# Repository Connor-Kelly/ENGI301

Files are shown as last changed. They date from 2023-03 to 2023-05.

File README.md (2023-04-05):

# Music Box
## Repo: 
This reposistory is fairly simple, docs are in /docs and source code in /src. There is also some royalty free music contained within the /sample_music directory, being used solely for testing purposes. There is also a /ipynb_testing_files directory which contains a variety of jupyter notebook files which can be used for easily testing and iterating through code.

## Story:
For my ENGI 301 project, I wanted to produce a self-contained music player box. Why would you want a self-contained music player? Why? When you have services like spotify and apple music, would you want something so dumb that you could develop it on your own?\
Well, I got a record player for Christmas, along with a collection of my grandparent's record collection. It's a cheaper one, definitely with worse sound quality than my JBL bluetooth speaker. However, when I played music on the record player, I found out how much I fiddle with my spotify playlist. I'm constantly changing the order, adding things to the queue, or just moving the volume. This is significantly more difficult on the record player, yet, it was nice to not be so worried about my music. With this project, I wanted to replicate this feeling, by making a player which is capable of playing premade playlists on a usb, rather than tracks on a record. Doing so, would allow for more playtime and customizability on the music to play further outside of what is pressed on a given record.\

My plan was to create an initial product which is as simple as this: Turn on, Select a playlist and songs, Play Music. 
In order to do this, I would need to create a navigable GUI which interacts with the hardware correctly, and is capable of calling music commands from button presses. 

## Environment:
In working on this project, I had to test different modules in 3 different environments. This was due to the lack of parts at the initial outset, and lack of portability of the pocketBeagle board.

First, on my personal laptop. My laptop is a Windows machine, and from here, I mainly did research, and outline/initial python code in VSCode. This is where I built the diagram for System, Software, Power, and GUI, which was done in Affinity Designer, a cheaper alternative to Illustrator.

Second, on my VM. On my laptop, using VirtualBox, I set up an Ubuntu VM. This offered a simple, reliable way to test things which had to occur in a linux environment, such as terminal commands, MOC, and python scripts.

Third, on the PocketBeagle board. This was by far the worst experience. The PocketBeagle, in my experience, was unreliable, inconvienient, and overall a pain in the rear. One major struggle is that the board is not really portable. You can stick it in your bag, but there's a pretty good chance that any wires on the breadboard are going to be messed up. Another issue is that the board is unreliable. As in, at this stage, I am on my third board (through no fault of my own). One board refused to read my SD card, while the other couldn't seem to read the data lines on the usb port. While this is part of embedded development, it's still a little frustrating, leading me to seek alternative environments, until hardware is strictly necessary.

## Music Software:
The plan for software was originally to use MPD (music player daemon). On initial testing, it quickly became apparent that this was a horrible idea. For me, it was far too complex, and it was nearly impossible to get a workable solution. Instead, I opted to use MOC (music on console), which is far less complex.\
I built a simple moc.py library which can be called as a python class, and encapsulates all the pieces needed to run mocp, as well as python aliases of the mocp terminal commands. While I got this working very well in my VM, I discovered later that the PocketBeagle doesn't like to play well with other devices, and it requires further testing to get working on the PocketBeagle.
## Visual Software:
For this project, I decided I would need to develop a GUI, and corresponding Hardware to run the GUI. For my screen, I used a LCD SPI screen from adafruit, and I used Pillow to build the GUI image files, and adafuit's drivers to run the screen.
The GUI library is segmented into 3 portions, a driver for the cursor / list selection, a modified spi_display driver, and a GUI driver, to coordinate the two, as well as set up buttons, underlays, and to call out to the moc driver.

## Hardware Drivers:
For driving the hardware. I first focused focused on the buttons. For some reason, I couldn't get threading to work, like we did in class, so, I instead wrote a simple event driven button that produces a callback:

```python
class EventButton():
    pin     = None
    edge    = None
    
    def __init__(self, pin, edge, callback):
        self.pin = pin
        self.edge = edge
        self.setup(callback)
    def setup(self, callback):
        # setup the pin
        GPIO.setup(self.pin, GPIO.IN)
        # setup the event handler
        GPIO.add_event_detect(gpio=self.pin, edge=self.edge, callback=callback)
```
From here, we can simply produce a callback to any class function via the prototype:
```python
class C():
    def func(args);

    btn = EventButton(gpio_pin, GPIO_action, lambda x: C.func(self, args))

# where gpio_pin is like "P1_18" for GPIO pin 18 in header P1, and 
# GPIO_action is one of the following: {GPIO.FALLING, GPIO.RISING, GPIO.BOTH}
```
With this basic functionality, I wrote handlers for each buttons within the GUI class.
## Working with the Rotary Encoder:
I wanted to get a rotary encoder working in order to be able to scroll through the cursor list.  For all the libraries I found, none of them worked, however, I found a raspberrypi rotary repo which I could convert to using BBIO.GPIO instead of the RPI.GPIO. While this appeared to work in software, the hardware did not seem to be cooperating; when looking at the sys/dev/gpio values in the PocketBeagle filesystem, no value bits seemed to be changing when moving the hardware. After struggling with it for some time, I gave up on this hardware portion, though the software driver is likely working.

## What I learned: 
 I am very familiar with software and thus familiar with Murphy's Law, but I think it should be extended for embedded systems to something to the affect: Anything that can go wrong, will go wrong, at the least convenient time, and it will be impossible to debug. 
I learned that debugging hardware and the os is a multilayered approach. For example, when setting up my USB on my second board, I found that the USB port had power, so I assumed that the data lines would be working. However, when running a `lsusb` command, I found that it didn't recognize my speaker. Where would one start debugging this issue? Honestly, my answer was to take it to my professor, and ask for help, but the answer was actually to get another board. 
I also learned that some things are just going to be magic. For example, the library which handles the rotary encoder is a piece of straight up bit magic. It uses the 4 low bits of a class integer to maintain the previous state of the encoder, pushes the new state bits onto the integer, and then uses states from 1 to 15 to determine the rotation direction which caused that state update. From looking at the algorithm, I just assumed that it was magic, and asked my professor why my encoder wasn't working. After he explained the algorithm, I think I understood how it worked, but we still could not get the encoder to work. 
I also learned that most things just aren't going to just work. When a port doesn't work, the first step is to perturb all the things associated with it. It should be re-plugged, any config files should be checked, the state should be reset, and any and all wire connections should be checked.

## What's left:
The cursor library still needs to be completed when it is given a correct target_list, this target_list would be a playlist or directory, which needs to be scrolled through. This has not been implemented, as I ran out of time working to get moc to work on the PocketBeagle, however, there exists a cursor.Cursor.cursor_select(), which should return a <str> target, which will then get called in moc like so moc.Moc.play_target(target), and direct the player to the target song.

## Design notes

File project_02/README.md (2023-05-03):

# PCB Design
This folder contains the data needed to make a music_box pcb. 
Built for the following project: https://www.hackster.io/connorkelly726/music-box-49702b

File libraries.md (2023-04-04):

# Libraries used in this repository:

## Python Libraries:
### core libraries:
time
subprocess
os
threading
### adafruit libraries:
busio
board
digitalio
color565
    adafruit_rgb_display 
adafruit_rgb_display.ili9341 
    as ili9341
Adafruit_BBIO.GPIO 
    as GPIO
### built libraries:
gui
cursor
spi_screen
event_button
mocp
### other python libraries:
from PIL import Image, ImageDraw, ImageFont

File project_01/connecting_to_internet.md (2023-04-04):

Share your computer’s WiFi / Internet connection (See above slides)

On PocketBeagle:

    sudo /sbin/route add default gw 192.168.7.1

Password for sudo is “temppwd”

    ping 8.8.8.8

Reply: PING 8.8.8.8 (8.8.8.8) 56(84) bytes of data.64 bytes from 8.8.8.8: icmp_seq=1 ttl=117 time=10.9 ms

sudo nano /etc/resolv.conf

Add line: nameserver 8.8.8.8

Exit nano: Ctrl-x (to eXit) → “Y” (for Yes) → <Enter> (to confirm file to write)

ping www.google.com

PING www.google.com (172.217.2.228) 56(84) bytes of data.

64 bytes from dfw28s01-in-f4.1e100.net (172.217.2.228): icmp_seq=1 ttl=51 time=10.9 ms

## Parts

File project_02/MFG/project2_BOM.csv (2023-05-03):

Qty | Value | Device | Package | Parts | Description | DESCRIPTION | MF | MP | PURCHASE-URL
5 | 10k | R_R0402 | R0402 | R1, R2, R3, R4, R5 | RESISTOR, American symbol |  | Bournes Inc
6 | FIDUCIAL | FIDUCIAL | FIDUCIAL_40MIL | FUD1, FUD2, FUD3, FUD4, FUD5, FUD6 |  |  | N/A
4 | MOUNTING_HOLE | MOUNTING_HOLE | MOUNTING_HOLE | MGT1, MGT2, MGT3, MGT4 | Chassis Mounting Hole w/GND connection ability |  | N/A
1 | PEC16-4015F-S0024 | PEC16-4015F-S0024 | PEC16-4015F-S0024 | ROT_SELECT | Mechanical Encoder Rotary Incremental Flat 0.02N.m Straight Quadrature Digital Square Wave 24PPR Through Hole PC Pin | Mechanical Encoder Rotary Incremental Flat 0.02N.m Straight Quadrature Digital Square Wave 24PPR Through Hole PC Pin | Bourns | PEC16-4015F-S0024 | https://pricing.snapeda.com/search/part/PEC16-4015F-S0024/?ref=eda
1 | POCKETBEAGLE | POCKETBEAGLE | POCKETBEAGLE | U$3 | PocketBeagle is an ultra-tiny-yet-complete open-source USB-key-fob computer. |  | BeagleBoard
1 | POTENTIOMETER | POTENTIOMETER | POT-PO90S | POT_VOLUME | 10k Ohm 1 Gang Linear Through Hole Potentiometer Detent 1.0 Kierros Conductive Plastic 0.03W, 1/32W PC Pins, Board Locks |  | TT Electronics/BI
4 | PUSH_BUTTON | PUSH_BUTTON | BUTTON_12.5MM | BTN_BACK, BTN_ON/OFF, BTN_PLAY/PAUSE, BTN_QUEUE | Momentary Press Button Switch |  | Adafruit
1 | SCREEN_2.8 | SCREEN_2.8 | SCREEN_2.8 | S1 | SPI Screen, TFT, 2.8in |  | Adafruit
1 | USB_A_BREAKOUT | USB_A_BREAKOUT | USB_A_BREAKOUT | U$5 | USB Breakout Board |  | SparkFun

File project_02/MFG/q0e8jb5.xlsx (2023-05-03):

Designator | Value | Footprint | Populate | MPN | Manufacturer
BTN_BACK | PUSH_BUTTON | BUTTON_12.5MM | 0 | B3F-1000 | Omron
BTN_ON/OFF | PUSH_BUTTON | BUTTON_12.5MM | 0 | B3F-1000 | Omron
BTN_PLAY/PAUSE | PUSH_BUTTON | BUTTON_12.5MM | 0 | B3F-1000 | Omron
BTN_QUEUE | PUSH_BUTTON | BUTTON_12.5MM | 0 | B3F-1000 | Omron
FUD1 | FIDUCIAL | FIDUCIAL_40MIL | 0
FUD2 | FIDUCIAL | FIDUCIAL_40MIL | 0
FUD3 | FIDUCIAL | FIDUCIAL_40MIL | 0
FUD4 | FIDUCIAL | FIDUCIAL_40MIL | 0
FUD5 | FIDUCIAL | FIDUCIAL_40MIL | 0
FUD6 | FIDUCIAL | FIDUCIAL_40MIL | 0
MGT1 | MOUNTING_HOLE | MOUNTING_HOLE | 0
MGT2 | MOUNTING_HOLE | MOUNTING_HOLE | 0
MGT3 | MOUNTING_HOLE | MOUNTING_HOLE | 0
MGT4 | MOUNTING_HOLE | MOUNTING_HOLE | 0
POT_VOLUME | POTENTIOMETER | POT-PO90S | 0 | 562 | Adafruit Industries
R1 | 10k | R0402 | 1 | MF-RES-0402-10K | MacroFab
R2 | 10k | R0402 | 1 | MF-RES-0402-10K | MacroFab
R3 | 10k | R0402 | 1 | MF-RES-0402-10K | MacroFab
R4 | 10k | R0402 | 1 | MF-RES-0402-10K | MacroFab
R5 | 10k | R0402 | 1 | MF-RES-0402-10K | MacroFab
ROT_SELECT | PEC16-4015F-S0024 | PEC16-4015F-S0024 | 0 | PEC16-4015F-S0024 | Bourns
S1 | SCREEN_2.8 | SCREEN_2.8 | 0
U$3 | POCKETBEAGLE | POCKETBEAGLE | 0 | POCKETBEAGLE | BeagleBoard
U$5 | USB_A_BREAKOUT | USB_A_BREAKOUT | 0 | BOB-12700 | SparkFun

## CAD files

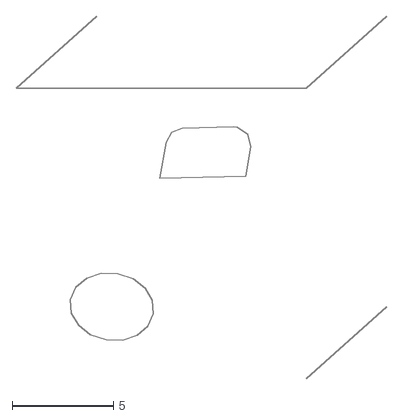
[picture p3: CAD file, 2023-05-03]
project_02/EAGLE/musicbox_logo.dxf
18.3 x 17.9

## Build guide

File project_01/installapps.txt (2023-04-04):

sudo apt-get install alsa-utils libasound2 –y

sudo apt-get install -y swig libpulse-dev libasound2-dev

sudo apt-get update

sudo pip3 install --upgrade Pillow

sudo pip3 install adafruit-circuitpython-busdevice

sudo pip3 install adafruit-circuitpython-rgb-display

sudo apt-get install ttf-dejavu -y

sudo apt-get install moc

pip3 install adafruit-circuitpython-ili9341

pip3 install rotaryio

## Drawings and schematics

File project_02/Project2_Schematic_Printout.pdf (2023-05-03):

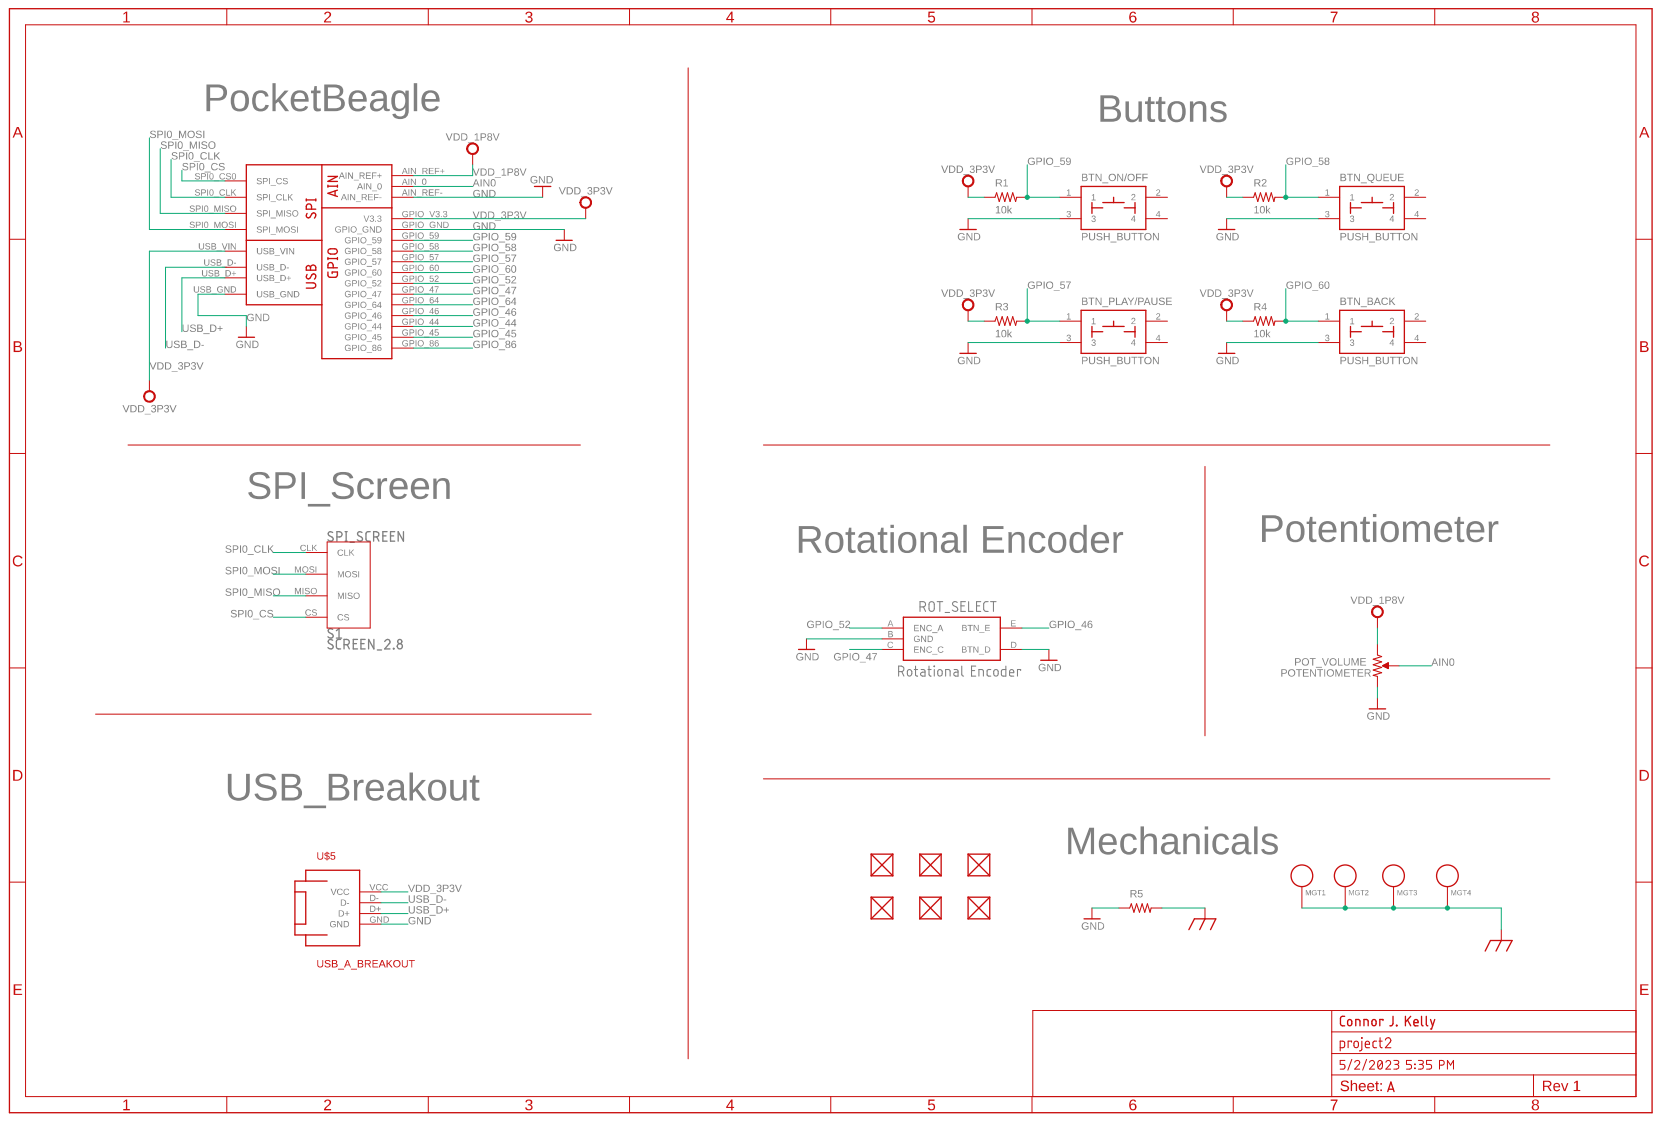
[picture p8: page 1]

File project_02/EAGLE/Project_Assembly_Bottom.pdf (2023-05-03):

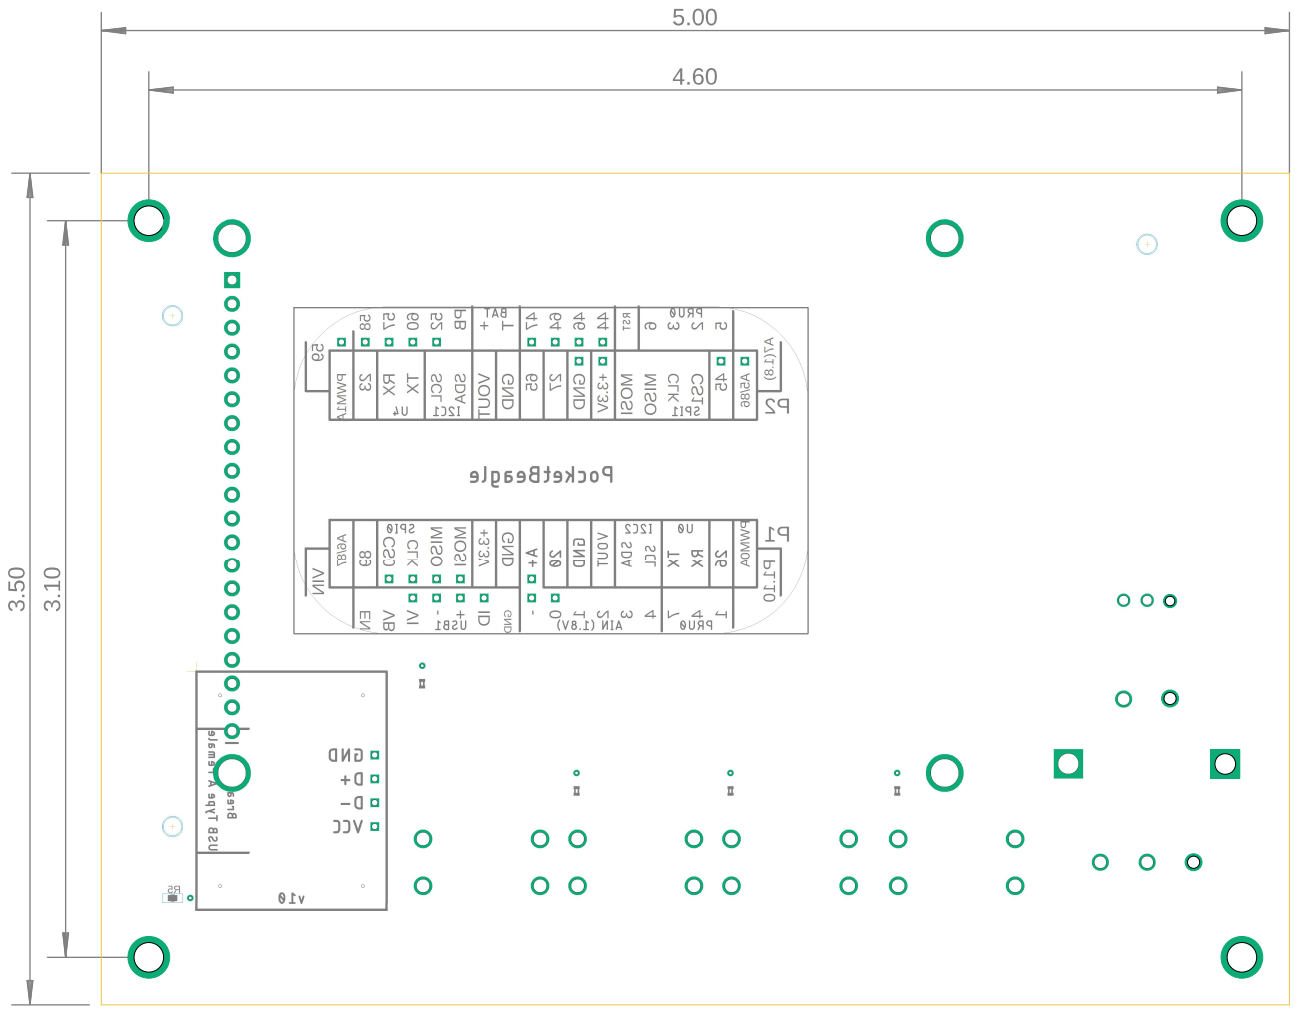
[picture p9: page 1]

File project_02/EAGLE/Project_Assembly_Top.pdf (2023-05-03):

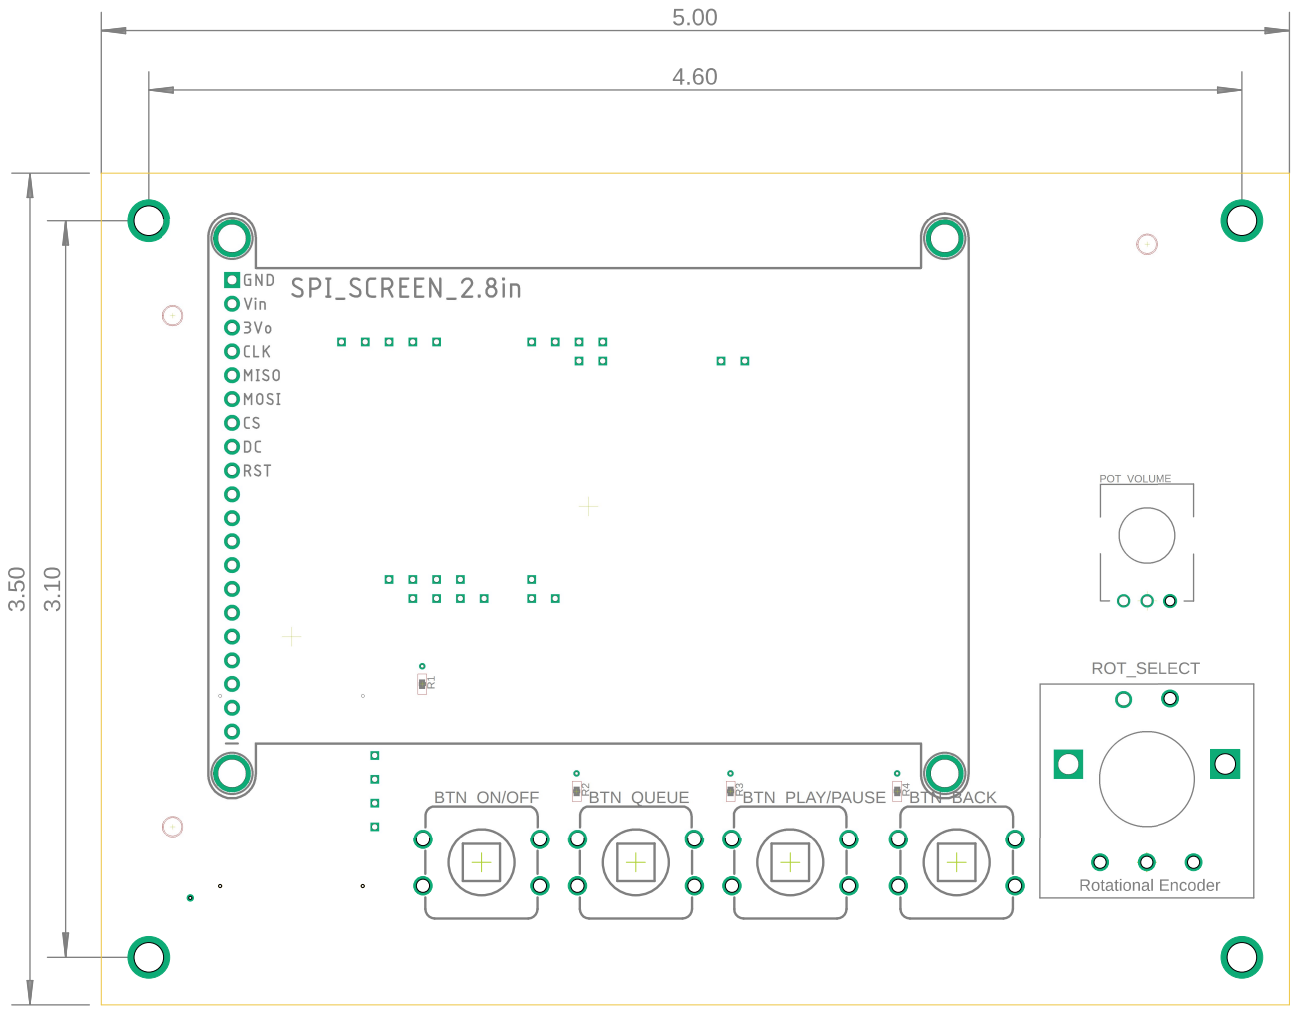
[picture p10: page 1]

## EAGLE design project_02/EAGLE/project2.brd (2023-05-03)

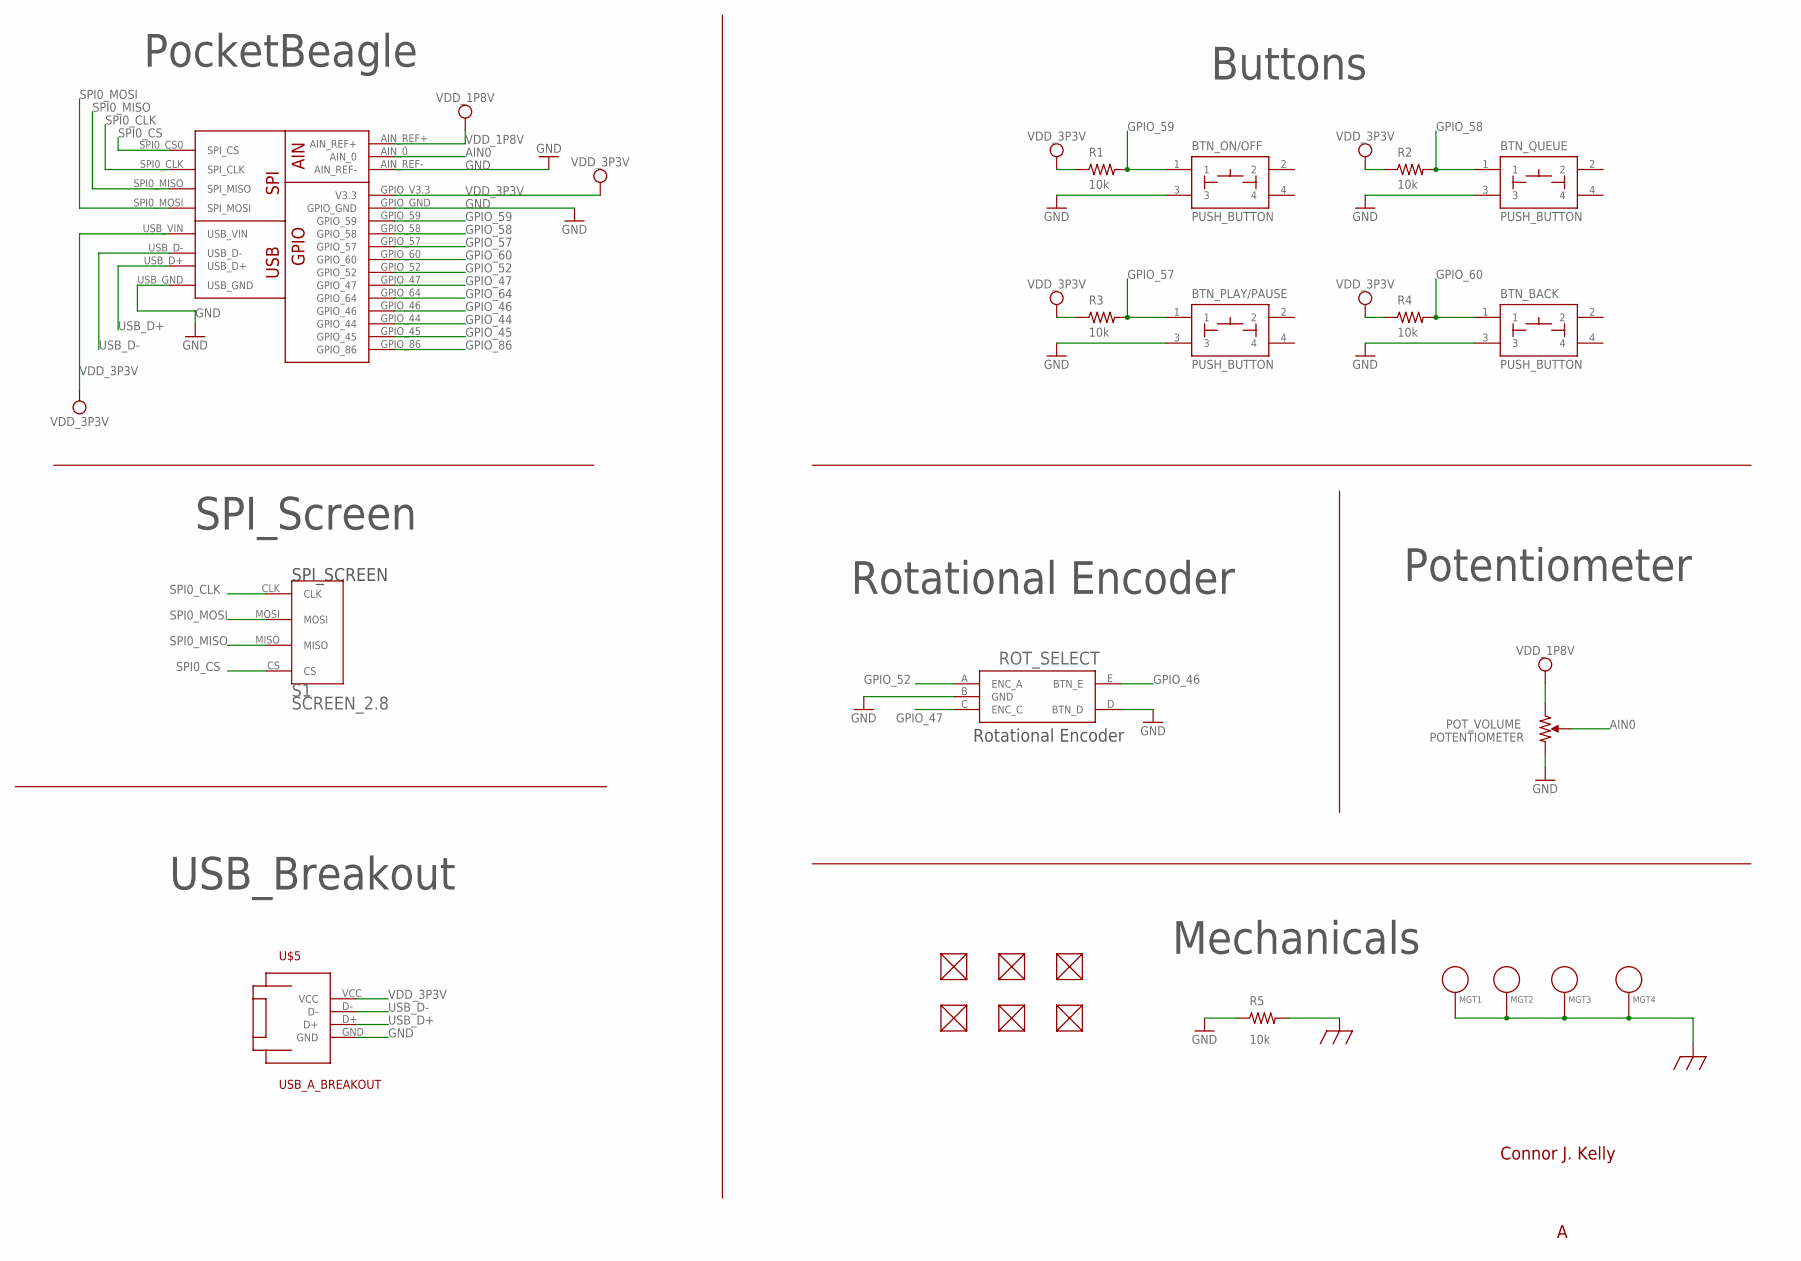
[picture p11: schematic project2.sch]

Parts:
BTN_BACK: PUSH_BUTTON; BUTTON_12.5MM
BTN_ON/OFF: PUSH_BUTTON; BUTTON_12.5MM
BTN_PLAY/PAUSE: PUSH_BUTTON; BUTTON_12.5MM
BTN_QUEUE: PUSH_BUTTON; BUTTON_12.5MM
FUD1, FUD2, FUD3, FUD4, FUD5, FUD6: FIDUCIAL; FIDUCIAL_40MIL
MGT1, MGT2, MGT3, MGT4: MOUNTING_HOLE
POT_VOLUME: POTENTIOMETER; POT-PO90S
R1, R2, R3, R4, R5: 10k; R0402
ROT_SELECT: PEC16-4015F-S0024
S1: SCREEN_2.8
U$3: POCKETBEAGLE
U$5: USB_A_BREAKOUT

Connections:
AIN0: POT_VOLUME.S, U$3.AIN_0
CGND: MGT1.P$1, MGT2.P$1, MGT3.P$1, MGT4.P$1, R5.2
GND: BTN_BACK.3, BTN_ON/OFF.3, BTN_PLAY/PAUSE.3, BTN_QUEUE.3, POT_VOLUME.CW, R5.1, ROT_SELECT.B (GND), ROT_SELECT.D (BTN_D), U$3.AIN_REF-, U$3.GPIO_GND, U$3.USB_GND, U$5.GND
GPIO_44: U$3.GPIO_44
GPIO_45: U$3.GPIO_45
GPIO_46: ROT_SELECT.E (BTN_E), U$3.GPIO_46
GPIO_47: ROT_SELECT.C (ENC_C), U$3.GPIO_47
GPIO_52: ROT_SELECT.A (ENC_A), U$3.GPIO_52
GPIO_57: BTN_PLAY/PAUSE.1, R3.2, U$3.GPIO_57
GPIO_58: BTN_QUEUE.1, R2.2, U$3.GPIO_58
GPIO_59: BTN_ON/OFF.1, R1.2, U$3.GPIO_59
GPIO_60: BTN_BACK.1, R4.2, U$3.GPIO_60
GPIO_64: U$3.GPIO_64
GPIO_86: U$3.GPIO_86
SPI0_CLK: S1.CLK, U$3.SPI0_CLK (SPI_CLK)
SPI0_CS: S1.CS, U$3.SPI0_CS0 (SPI_CS)
SPI0_MISO: S1.MISO, U$3.SPI0_MISO (SPI_MISO)
SPI0_MOSI: S1.MOSI, U$3.SPI0_MOSI (SPI_MOSI)
USB_D+: U$3.USB_D+, U$5.D+
USB_D-: U$3.USB_D-, U$5.D-
VDD_1P8V: POT_VOLUME.CCW, U$3.AIN_REF+
VDD_3P3V: R1.1, R2.1, R3.1, R4.1, U$3.GPIO_V3.3 (V3.3), U$3.USB_VIN, U$5.VCC

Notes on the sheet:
Buttons
Rotational Encoder
Potentiometer
Mechanicals
USB_Breakout
SPI_Screen
PocketBeagle
Connor J. Kelly

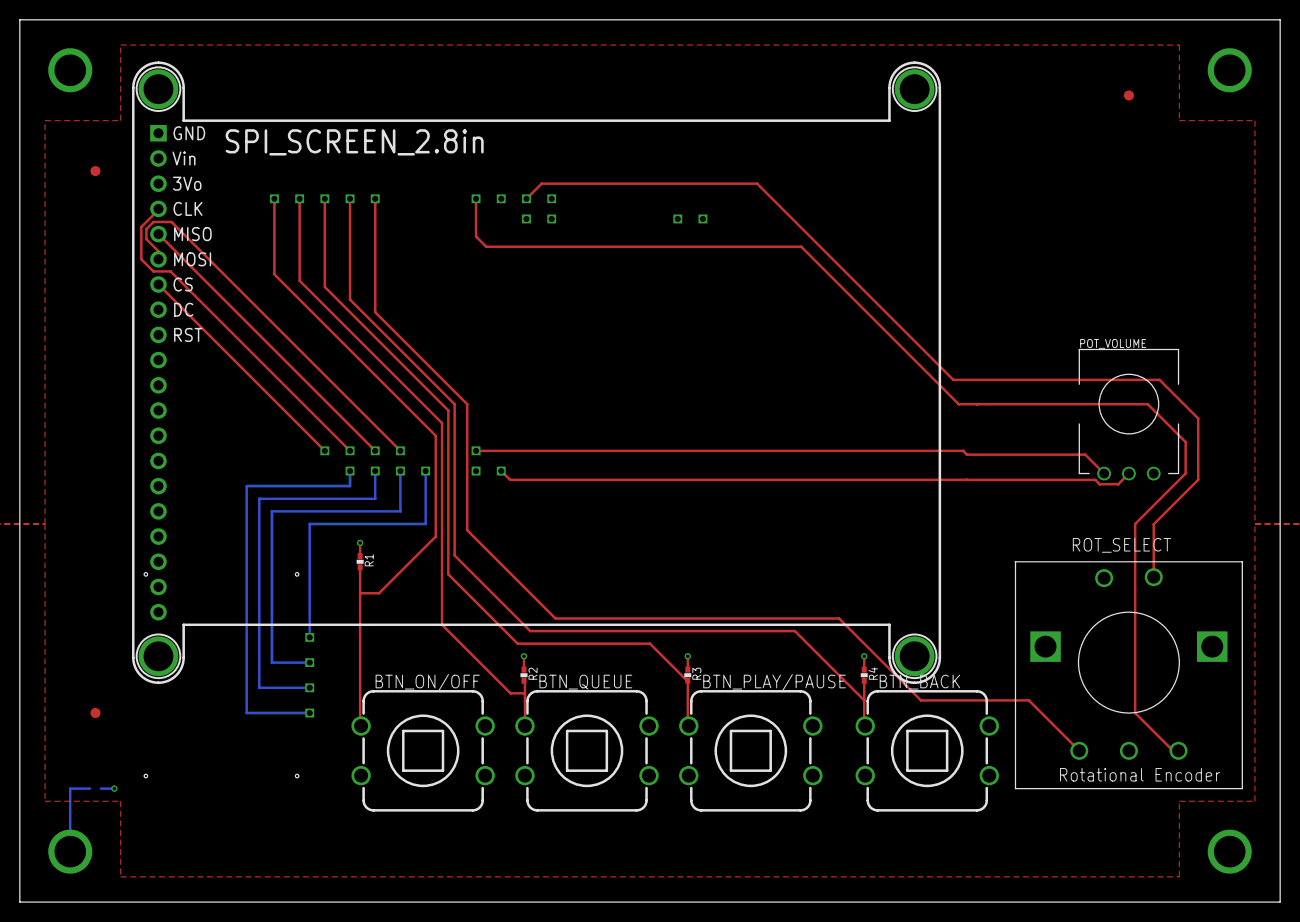
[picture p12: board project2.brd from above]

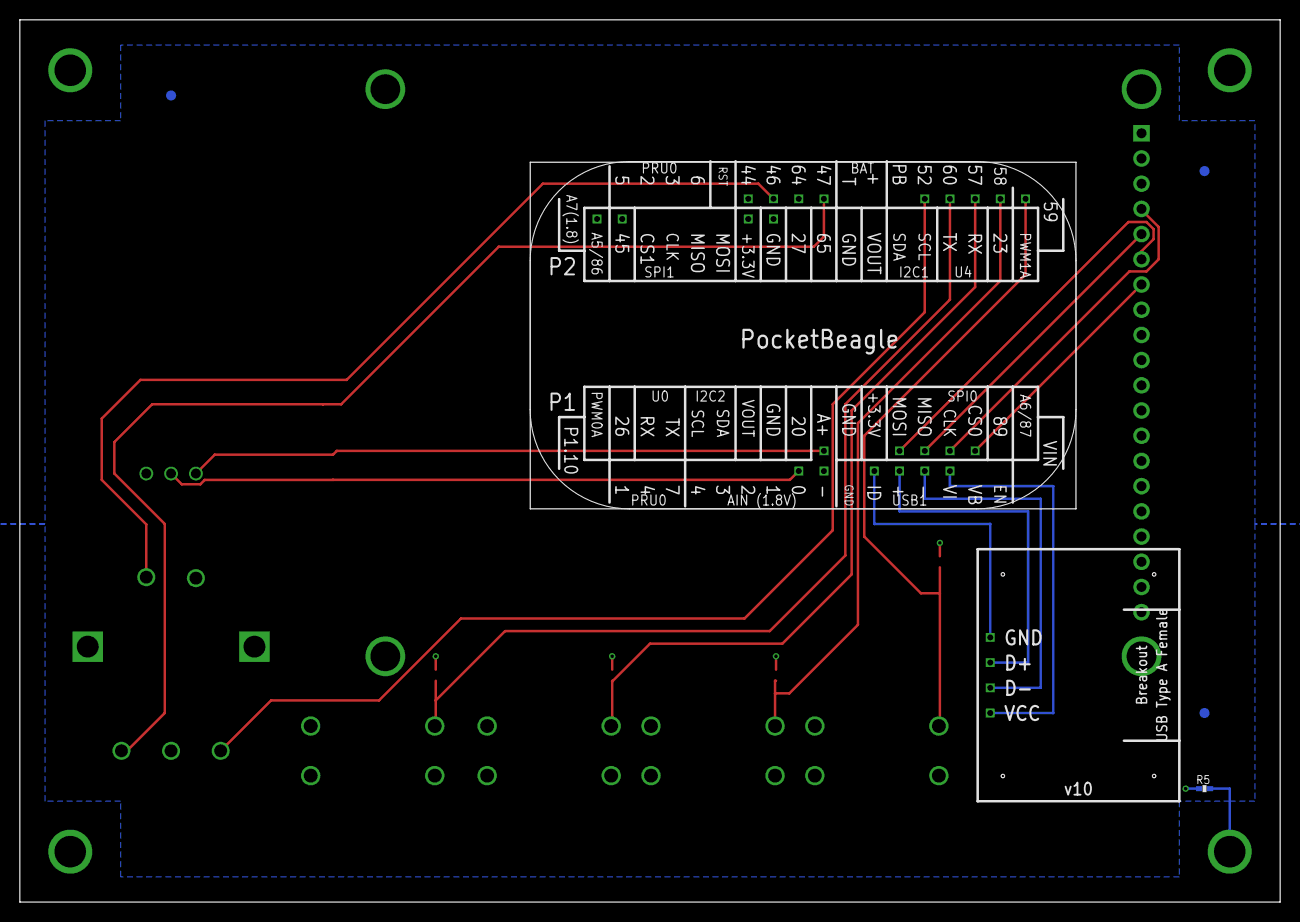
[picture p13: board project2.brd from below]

Board: 4 copper layers, 127.0 x 88.9 mm, 24 parts (7 on the bottom side), 18 nets.

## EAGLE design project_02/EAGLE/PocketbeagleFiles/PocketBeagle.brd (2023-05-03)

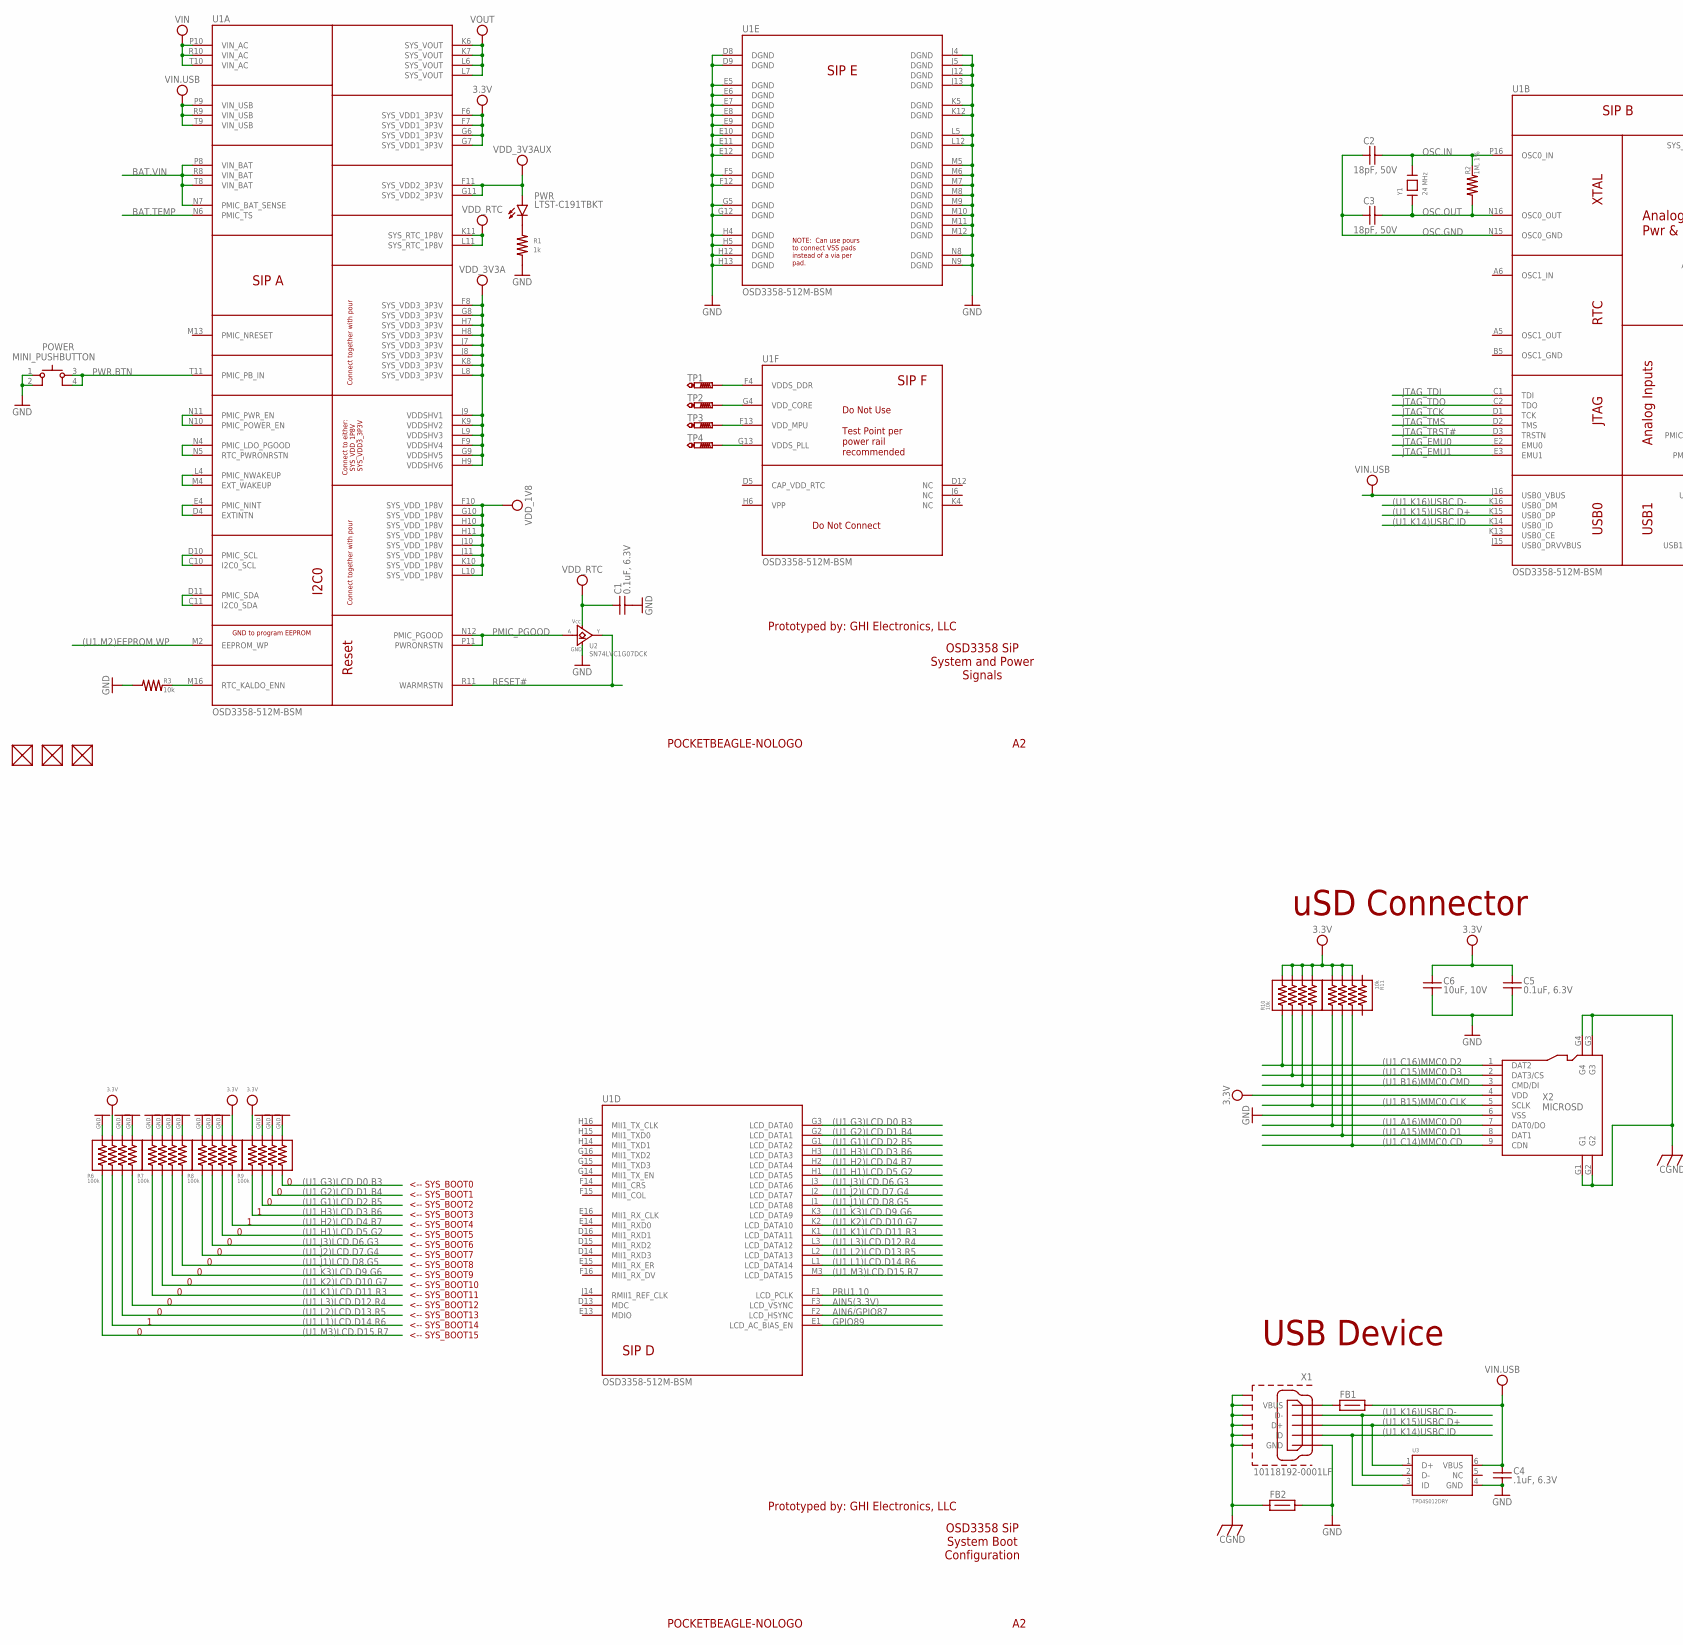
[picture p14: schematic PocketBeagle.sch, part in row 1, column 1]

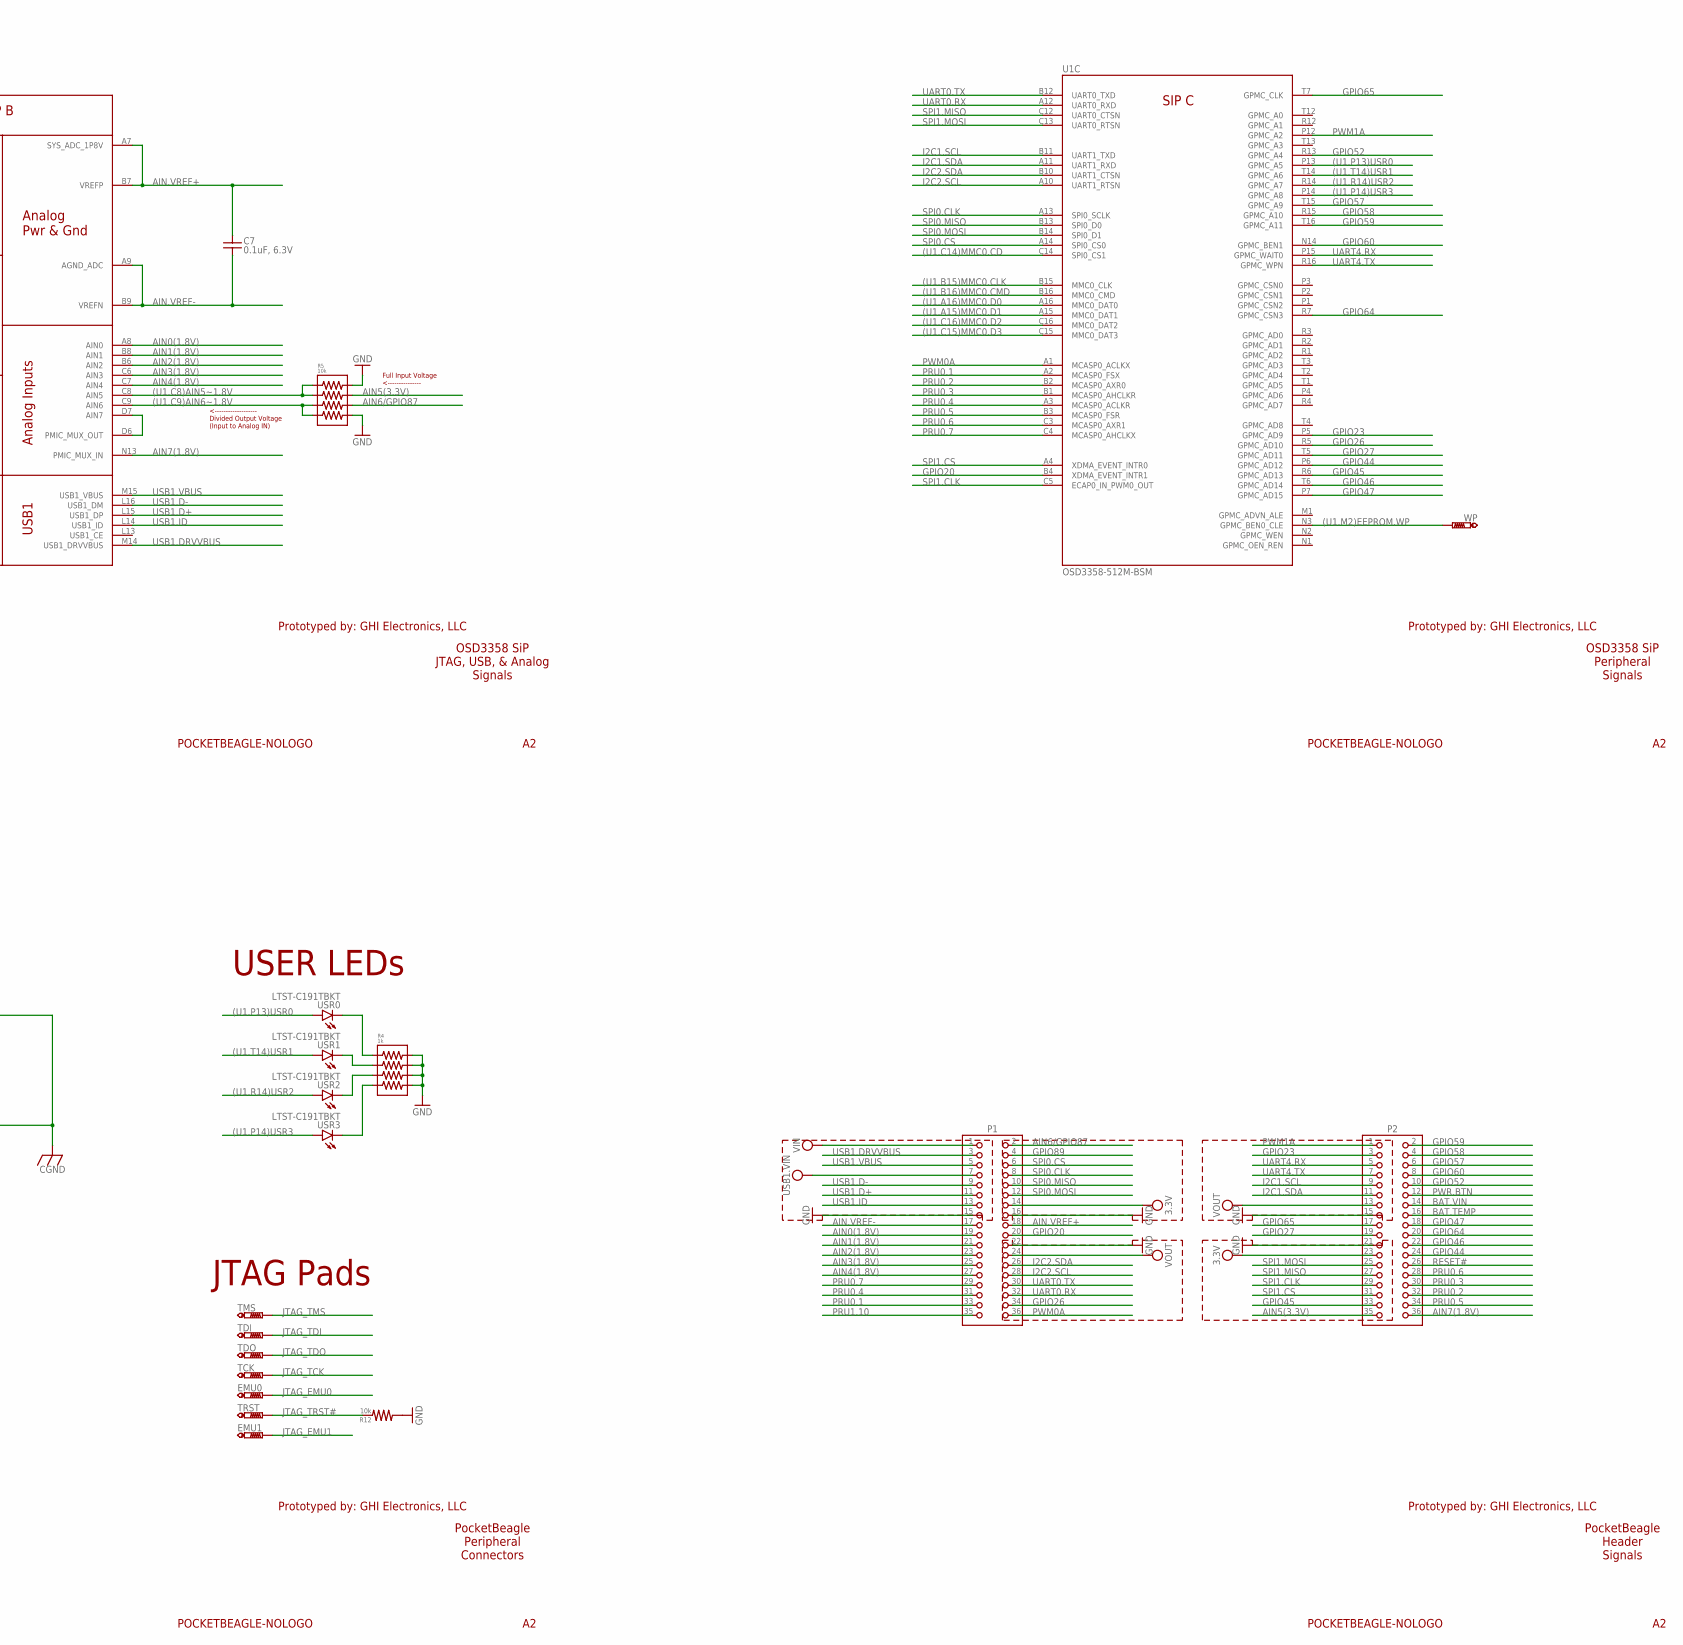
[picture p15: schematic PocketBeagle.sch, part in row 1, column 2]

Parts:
C1, C5, C7: 0.1uF, 6.3V; 0402
C2, C3: 18pF, 50V; 0402
C4: .1uF, 6.3V; 0402
C6: 10uF, 10V; 0603
EMU0, EMU1: PTR1B1,27; B1,27
FB1, FB2: FB-(INCH)-0603; 0603
FUD1, FUD2, FUD3: FIDUCIAL; FIDUCIAL_40MIL
P1, P2: 2X18-(INCH)-0.1-TH-(35MIL-DIA)-W/O-SILK; TH-2X18-(35MIL-DIA)-W/O-SILK
POWER: MINI_PUSHBUTTON
PWR: LTST-C191TBKT; 0603-LED
R1: 1k; 0402
R2: 1M, 1%; 0402
R3, R12: 10k; 0402
R4: 1k; RN0804
R5, R10, R11: 10k; RN0804
R6, R7, R8, R9: 100k; RN0804
TCK: PTR1B1,27; B1,27
TDI: PTR1B1,27; B1,27
TDO: PTR1B1,27; B1,27
TMS: PTR1B1,27; B1,27
TP1, TP2, TP3, TP4: PTR1B1,27; B1,27
TRST: PTR1B1,27; B1,27
U1: OSD3358-512M-BSM; OSD335X-BGA-256
U2: SN74LVC1G07DCK; SC70(TI-DCK)
U3: TPD4S012DRY; SON-6(TI)-DRY
USR0, USR1, USR2, USR3: LTST-C191TBKT; 0603-LED
WP: PTR1B1,27; B1,27
X1: 10118192-0001LF; 10118192-0001LF(MICRO-USB-B-AMPHENOL-FCI)
X2: MICROSD
Y1: 24 MHz; CRYSTAL_5X3.2MM

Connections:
3.3V: C5.1, C6.1, P1.14, P2.23, R6.7, R8.5, R9.4, R10.5, R10.6, R10.7, R10.8, R11.2, R11.3, R11.4, U1.F6 (SYS_VDD1_3P3V), U1.F7 (SYS_VDD1_3P3V), U1.G6 (SYS_VDD1_3P3V), U1.G7 (SYS_VDD1_3P3V), X2.4 (VDD)
(U1.A15)MMC0.D1: R11.6, U1.A15 (MMC0_DAT1), X2.8 (DAT1)
(U1.A16)MMC0.D0: R11.5, U1.A16 (MMC0_DAT0), X2.7 (DAT0/DO)
(U1.B15)MMC0.CLK: R10.4, U1.B15 (MMC0_CLK), X2.5 (SCLK)
(U1.B16)MMC0.CMD: R10.3, U1.B16 (MMC0_CMD), X2.3 (CMD/DI)
(U1.C8)AIN5~1.8V: R5.1, R5.2, U1.C8 (AIN5)
(U1.C9)AIN6~1.8V: R5.3, R5.4, U1.C9 (AIN6)
(U1.C14)MMC0.CD: R11.7, U1.C14 (SPI0_CS1), X2.9 (CDN)
(U1.C15)MMC0.D3: R10.2, U1.C15 (MMC0_DAT3), X2.2 (DAT3/CS)
(U1.C16)MMC0.D2: R10.1, U1.C16 (MMC0_DAT2), X2.1 (DAT2)
(U1.G1)LCD.D2.B5: R9.6, U1.G1 (LCD_DATA2)
(U1.G2)LCD.D1.B4: R9.7, U1.G2 (LCD_DATA1)
(U1.G3)LCD.D0.B3: R9.8, U1.G3 (LCD_DATA0)
(U1.H1)LCD.D5.G2: R8.3, U1.H1 (LCD_DATA5)
(U1.H2)LCD.D4.B7: R8.4, U1.H2 (LCD_DATA4)
(U1.H3)LCD.D3.B6: R9.5, U1.H3 (LCD_DATA3)
(U1.J1)LCD.D8.G5: R7.4, U1.J1 (LCD_DATA8)
(U1.J2)LCD.D7.G4: R8.1, U1.J2 (LCD_DATA7)
(U1.J3)LCD.D6.G3: R8.2, U1.J3 (LCD_DATA6)
(U1.K1)LCD.D11.R3: R7.1, U1.K1 (LCD_DATA11)
(U1.K2)LCD.D10.G7: R7.2, U1.K2 (LCD_DATA10)
(U1.K3)LCD.D9.G6: R7.3, U1.K3 (LCD_DATA9)
(U1.K14)USBC.ID: U1.K14 (USB0_ID), U3.3 (ID), X1.ID
(U1.K15)USBC.D+: U1.K15 (USB0_DP), U3.1 (D+), X1.D+
(U1.K16)USBC.D-: U1.K16 (USB0_DM), U3.2 (D-), X1.D-
(U1.L1)LCD.D14.R6: R6.2, U1.L1 (LCD_DATA14)
(U1.L2)LCD.D13.R5: R6.3, U1.L2 (LCD_DATA13)
(U1.L3)LCD.D12.R4: R6.4, U1.L3 (LCD_DATA12)
(U1.M2)EEPROM.WP: U1.M2 (EEPROM_WP), U1.N3 (GPMC_BEN0_CLE), WP.TP
(U1.M3)LCD.D15.R7: R6.1, U1.M3 (LCD_DATA15)
(U1.P13)USR0: U1.P13 (GPMC_A5), USR0.A
(U1.P14)USR3: U1.P14 (GPMC_A8), USR3.A
(U1.R14)USR2: U1.R14 (GPMC_A7), USR2.A
(U1.T14)USR1: U1.T14 (GPMC_A6), USR1.A
AIN0(1.8V): P1.19, U1.A8 (AIN0)
AIN1(1.8V): P1.21, U1.B8 (AIN1)
AIN2(1.8V): P1.23, U1.B6 (AIN2)
AIN3(1.8V): P1.25, U1.C6 (AIN3)
AIN4(1.8V): P1.27, U1.C7 (AIN4)
AIN5(3.3V): P2.35, R5.7, U1.F3 (LCD_VSYNC)
AIN6/GPIO87: P1.2, R5.6, U1.F2 (LCD_HSYNC)
AIN7(1.8V): P2.36, U1.N13 (PMIC_MUX_IN)
AIN.VREF+: C7.1, P1.18, U1.A7 (SYS_ADC_1P8V), U1.B7 (VREFP)
AIN.VREF-: C7.2, P1.17, U1.A9 (AGND_ADC), U1.B9 (VREFN)
BAT.TEMP: P2.16, U1.N6 (PMIC_TS)
BAT.VIN: P2.14, U1.N7 (PMIC_BAT_SENSE), U1.P8 (VIN_BAT), U1.R8 (VIN_BAT), U1.T8 (VIN_BAT)
CGND: FB2.1, X1.CGND1 (SGND1), X1.CGND2 (SGND2), X1.CGND3 (SGND3), X1.CGND4 (SGND4), X1.CGND5 (SGND5), X1.CGND6 (SGND6), X2.G1, X2.G2, X2.G3, X2.G4
GND: C1.2, C4.2, C5.2, C6.2, FB2.2, P1.15, P1.16, P1.22, P2.15, P2.21, POWER.1, POWER.2, R1.1, R3.1, R4.5, R4.6, R4.7, R4.8, R5.5, R5.8, R6.5, R6.6, R6.8, R7.5, R7.6, R7.7, R7.8, R8.6, R8.7, R8.8, R9.1, R9.2, R9.3, R12.1, U1.D8 (DGND), U1.D9 (DGND), U1.E5 (DGND), U1.E6 (DGND), U1.E7 (DGND), U1.E8 (DGND), U1.E9 (DGND), U1.E10 (DGND), U1.E11 (DGND), U1.E12 (DGND), U1.F5 (DGND), U1.F12 (DGND), U1.G5 (DGND), U1.G12 (DGND), U1.H4 (DGND), U1.H5 (DGND), U1.H12 (DGND), U1.H13 (DGND), U1.J4 (DGND), U1.J5 (DGND), U1.J12 (DGND), U1.J13 (DGND), U1.K5 (DGND), U1.K12 (DGND), U1.L5 (DGND), U1.L12 (DGND), U1.M5 (DGND), U1.M6 (DGND), U1.M7 (DGND), U1.M8 (DGND), U1.M9 (DGND), U1.M10 (DGND), U1.M11 (DGND), U1.M12 (DGND), U1.N8 (DGND), U1.N9 (DGND), U2.3 (GND), U3.4 (GND), X1.GND, X2.6 (VSS)
GPIO20: P1.20, U1.B4 (XDMA_EVENT_INTR1)
GPIO23: P2.3, U1.P5 (GPMC_AD9)
GPIO26: P1.34, U1.R5 (GPMC_AD10)
GPIO27: P2.19, U1.T5 (GPMC_AD11)
GPIO44: P2.24, U1.P6 (GPMC_AD12)
GPIO45: P2.33, U1.R6 (GPMC_AD13)
GPIO46: P2.22, U1.T6 (GPMC_AD14)
GPIO47: P2.18, U1.P7 (GPMC_AD15)
GPIO52: P2.10, U1.R13 (GPMC_A4)
GPIO57: P2.6, U1.T15 (GPMC_A9)
GPIO58: P2.4, U1.R15 (GPMC_A10)
GPIO59: P2.2, U1.T16 (GPMC_A11)
GPIO60: P2.8, U1.N14 (GPMC_BEN1)
GPIO64: P2.20, U1.R7 (GPMC_CSN3)
GPIO65: P2.17, U1.T7 (GPMC_CLK)
GPIO89: P1.4, U1.E1 (LCD_AC_BIAS_EN)
I2C1.SCL: P2.9, U1.B11 (UART1_TXD)
I2C1.SDA: P2.11, U1.A11 (UART1_RXD)
I2C2.SCL: P1.28, U1.A10 (UART1_RTSN)
I2C2.SDA: P1.26, U1.B10 (UART1_CTSN)
JTAG_EMU0: EMU0.TP, U1.E2 (EMU0)
JTAG_EMU1: EMU1.TP, U1.E3 (EMU1)
JTAG_TCK: TCK.TP, U1.D1 (TCK)
JTAG_TDI: TDI.TP, U1.C1 (TDI)
JTAG_TDO: TDO.TP, U1.C2 (TDO)
JTAG_TMS: TMS.TP, U1.D2 (TMS)
JTAG_TRST#: R12.2, TRST.TP, U1.D3 (TRSTN)
unnamed: R4.3, USR2.K
unnamed: R4.4, USR3.K
unnamed: PWR.K, R1.2
unnamed: R4.2, USR1.K
unnamed: R4.1, USR0.K
unnamed: TP1.TP, U1.F4 (VDDS_DDR)
unnamed: TP2.TP, U1.G4 (VDD_CORE)
unnamed: TP3.TP, U1.F13 (VDD_MPU)
unnamed: TP4.TP, U1.G13 (VDDS_PLL)
unnamed: U1.D6 (PMIC_MUX_OUT), U1.D7 (AIN7)
unnamed: R3.2, U1.M16 (RTC_KALDO_ENN)
unnamed: U1.N4 (PMIC_LDO_PGOOD), U1.N5 (RTC_PWRONRSTN)
unnamed: U1.L4 (PMIC_NWAKEUP), U1.M4 (EXT_WAKEUP)
unnamed: U1.D4 (EXTINTN), U1.E4 (PMIC_NINT)
unnamed: U1.N10 (PMIC_POWER_EN), U1.N11 (PMIC_PWR_EN)
unnamed: U1.C11 (I2C0_SDA), U1.D11 (PMIC_SDA)
unnamed: U1.C10 (I2C0_SCL), U1.D10 (PMIC_SCL)
OSC.GND: C2.1, C3.1, U1.N15 (OSC0_GND)
OSC.IN: C2.2, R2.2, U1.P16 (OSC0_IN), Y1.2
OSC.OUT: C3.2, R2.1, U1.N16 (OSC0_OUT), Y1.1
PMIC_PGOOD: U1.N12 (PMIC_PGOOD), U1.P11 (PWRONRSTN), U2.2 (A)
PRU0.1: P1.33, U1.A2 (MCASP0_FSX)
PRU0.2: P2.32, U1.B2 (MCASP0_AXR0)
PRU0.3: P2.30, U1.B1 (MCASP0_AHCLKR)
PRU0.4: P1.31, U1.A3 (MCASP0_ACLKR)
PRU0.5: P2.34, U1.B3 (MCASP0_FSR)
PRU0.6: P2.28, U1.C3 (MCASP0_AXR1)
PRU0.7: P1.29, U1.C4 (MCASP0_AHCLKX)
PRU1.10: P1.35, U1.F1 (LCD_PCLK)
PWM0A: P1.36, U1.A1 (MCASP0_ACLKX)
PWM1A: P2.1, U1.P12 (GPMC_A2)
PWR.BTN: P2.12, POWER.3, POWER.4, U1.T11 (PMIC_PB_IN)
RESET#: P2.26, U1.R11 (WARMRSTN), U2.4 (Y)
SPI0.CLK: P1.8, U1.A13 (SPI0_SCLK)
SPI0.CS: P1.6, U1.A14 (SPI0_CS0)
SPI0.MISO: P1.10, U1.B13 (SPI0_D0)
SPI0.MOSI: P1.12, U1.B14 (SPI0_D1)
SPI1.CLK: P2.29, U1.C5 (ECAP0_IN_PWM0_OUT)
SPI1.CS: P2.31, U1.A4 (XDMA_EVENT_INTR0)
SPI1.MISO: P2.27, U1.C12 (UART0_CTSN)
SPI1.MOSI: P2.25, U1.C13 (UART0_RTSN)
UART0.RX: P1.32, U1.A12 (UART0_RXD)
UART0.TX: P1.30, U1.B12 (UART0_TXD)
UART4.RX: P2.5, U1.P15 (GPMC_WAIT0)
UART4.TX: P2.7, U1.R16 (GPMC_WPN)
USB1.D+: P1.11, U1.L15 (USB1_DP)
USB1.D-: P1.9, U1.L16 (USB1_DM)
USB1.DRVVBUS: P1.3, U1.M14 (USB1_DRVVBUS)
USB1.ID: P1.13, U1.L14 (USB1_ID)
USB1.VBUS: P1.5, U1.M15 (USB1_VBUS)
VBUS.RAW: FB1.1, X1.VBUS
VDD_1V8: U1.F10 (SYS_VDD_1P8V), U1.G10 (SYS_VDD_1P8V), U1.H10 (SYS_VDD_1P8V), U1.H11 (SYS_VDD_1P8V), U1.J10 (SYS_VDD_1P8V), U1.J11 (SYS_VDD_1P8V), U1.K10 (SYS_VDD_1P8V), U1.L10 (SYS_VDD_1P8V)
VDD_3V3A: U1.F8 (SYS_VDD3_3P3V), U1.F9 (VDDSHV4), U1.G8 (SYS_VDD3_3P3V), U1.G9 (VDDSHV5), U1.H7 (SYS_VDD3_3P3V), U1.H8 (SYS_VDD3_3P3V), U1.H9 (VDDSHV6), U1.J7 (SYS_VDD3_3P3V), U1.J8 (SYS_VDD3_3P3V), U1.J9 (VDDSHV1), U1.K8 (SYS_VDD3_3P3V), U1.K9 (VDDSHV2), U1.L8 (SYS_VDD3_3P3V), U1.L9 (VDDSHV3)
VDD_3V3AUX: PWR.A, U1.F11 (SYS_VDD2_3P3V), U1.G11 (SYS_VDD2_3P3V)
VDD_RTC: C1.1, U1.K11 (SYS_RTC_1P8V), U1.L11 (SYS_RTC_1P8V), U2.5 (VCC)
VIN: P1.1, U1.P10 (VIN_AC), U1.R10 (VIN_AC), U1.T10 (VIN_AC)
VIN.USB: C4.1, FB1.2, P1.7, U1.J16 (USB0_VBUS), U1.P9 (VIN_USB), U1.R9 (VIN_USB), U1.T9 (VIN_USB), U3.6 (VBUS)
VOUT: P1.24, P2.13, U1.K6 (SYS_VOUT), U1.K7 (SYS_VOUT), U1.L6 (SYS_VOUT), U1.L7 (SYS_VOUT)

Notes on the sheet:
<-- SYS_BOOT0 <-- SYS_BOOT1 <-- SYS_BOOT2 <-- SYS_BOOT3 <-- SYS_BOOT4 <-- SYS_BOOT5 <-- SYS_BOOT6 <-- SYS_BOOT7 <-- SYS_BOOT8 <-- SYS_BOOT9 <-- SYS_BOOT10 <-- SYS_BOOT11 <-- SYS_BOOT12 <-- SYS_BOOT13 <-- SYS_BOOT14 <-- SYS_BOOT15
USB Device
USER LEDs
uSD Connector
OSD3358 SiP System and Power Signals
Prototyped by: GHI Electronics, LLC
POCKETBEAGLE-NOLOGO
Full Input Voltage <---------------
<------------------- Divided Output Voltage (Input to Analog IN)
OSD3358 SiP JTAG, USB, & Analog Signals
OSD3358 SiP Peripheral Signals
OSD3358 SiP System Boot Configuration
PocketBeagle Peripheral Connectors
PocketBeagle Header Signals
JTAG Pads

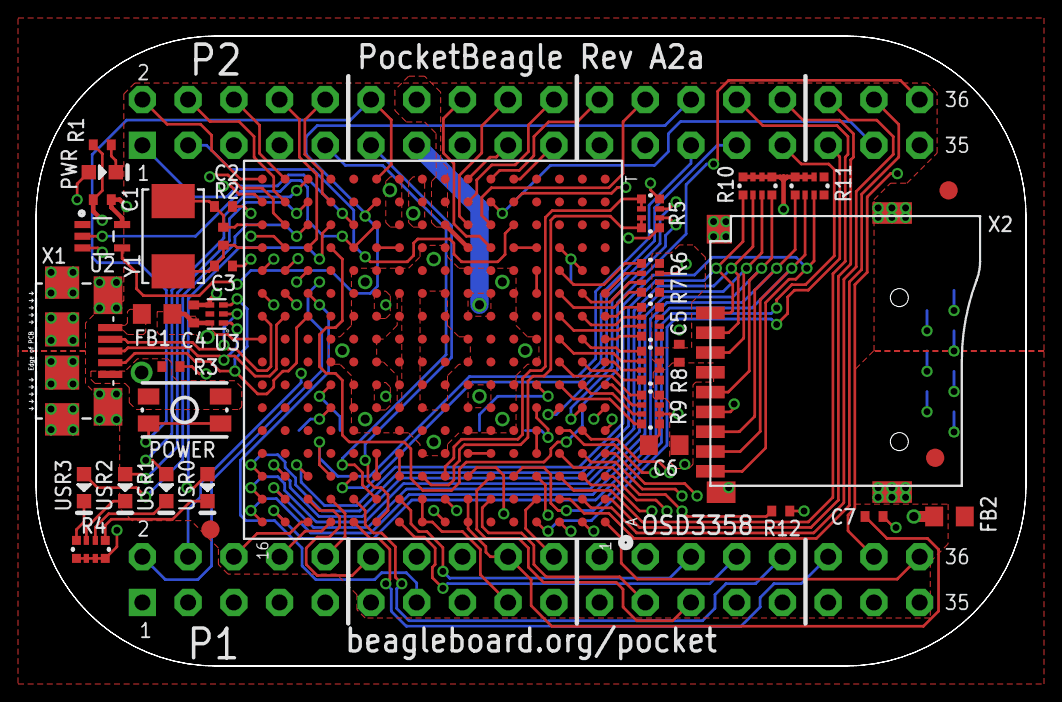
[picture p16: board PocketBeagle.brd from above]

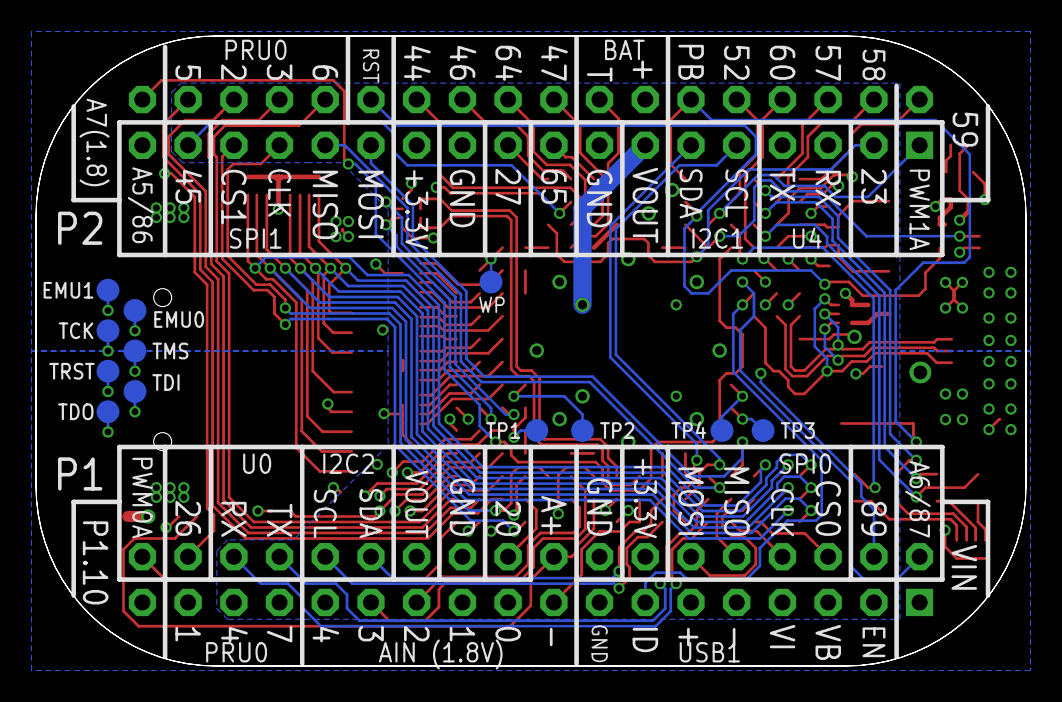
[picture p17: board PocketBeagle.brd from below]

Board: 4 copper layers, 55.0 x 35.0 mm, 50 parts (12 on the bottom side), 133 nets.

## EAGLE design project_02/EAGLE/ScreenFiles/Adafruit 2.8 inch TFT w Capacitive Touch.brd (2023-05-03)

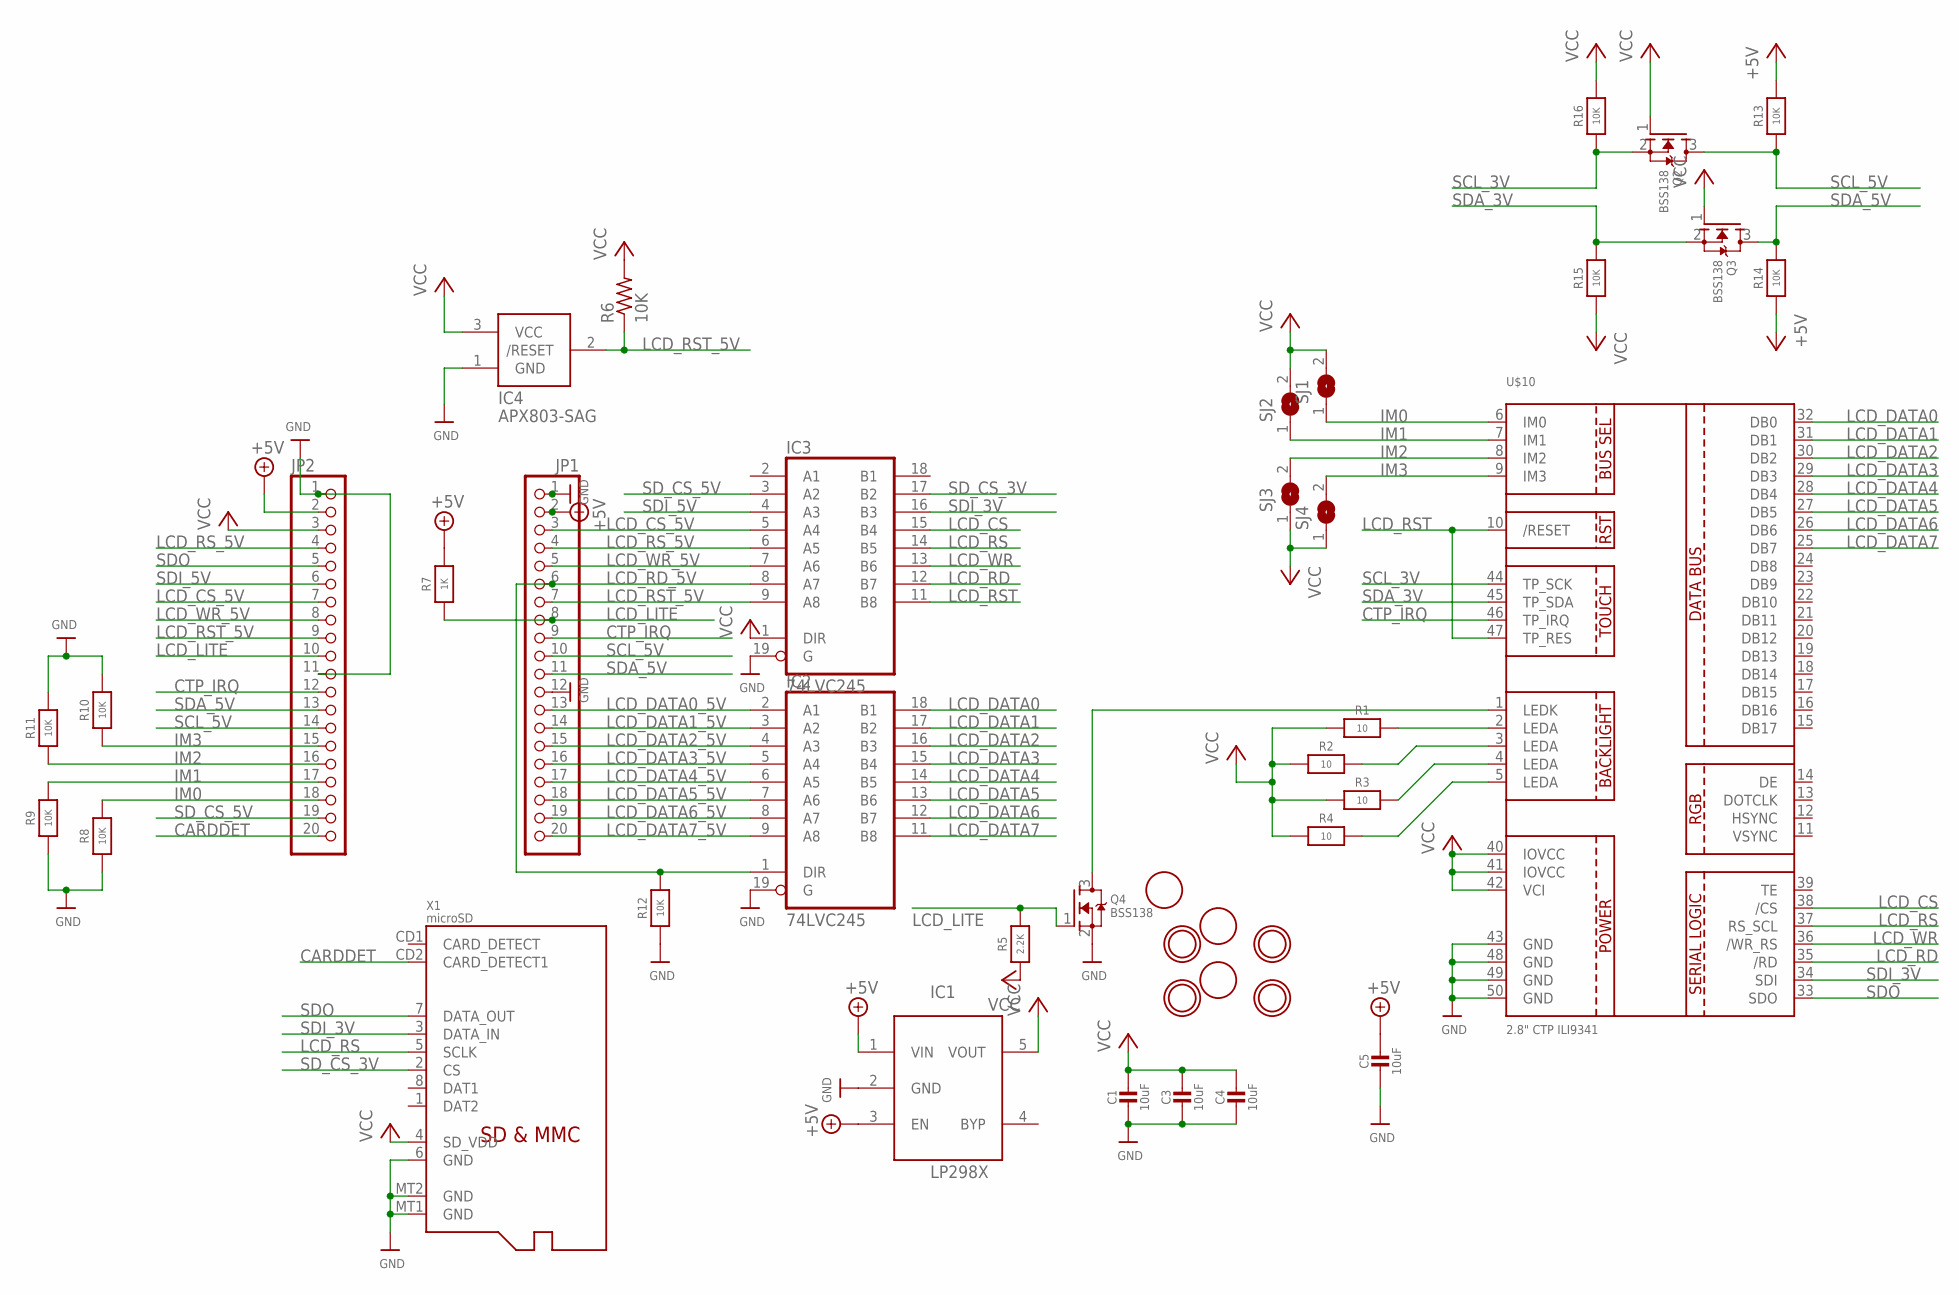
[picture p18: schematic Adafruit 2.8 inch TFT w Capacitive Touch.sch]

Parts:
C1, C3, C4, C5: 10uF; 0805-NO
IC1: MIC5225-3.3; SOT23-5L
IC2, IC3: 74LVC245; SO20W
IC4: APX803-SAG; SOT23
JP1, JP2: HEADER-1X20ROUND; 1X20_ROUND
Q2, Q3, Q4: BSS138; SOT23-WIDE
R1, R2, R3, R4: 10; 0805-NO
R5: 2.2K; 0805-NO
R6: 10K; R0805
R7: 1K; 0805-NO
R8, R9, R10, R11, R12, R13, R14, R15, R16: 10K; 0805-NO
SJ1, SJ2, SJ3, SJ4: SOLDERJUMPER; SOLDERJUMPER_ARROW_NOPASTE
U$7, U$15, U$16, U$17: MOUNTINGHOLE3.0THIN; MOUNTINGHOLE_3.0_PLATEDTHIN
U$9, U$11, U$23: FIDUCIAL; FIDUCIAL_1MM
U$10: 2.8" CTP ILI9341; TFT_2.83IN_240X320_50PIN
X1: microSD; MICROSD

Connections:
+5V: C5.1, IC1.1 (VIN), IC1.3 (EN), JP1.2, JP2.2, R7.2, R13.2, R14.1
CARDDET: JP2.20, X1.CD2 (CARD_DETECT1)
CTP_IRQ: JP1.9, JP2.12, U$10.46 (TP_IRQ)
GND: C1.2, C3.2, C4.2, C5.2, IC1.2 (GND), IC2.10 (GND), IC2.19 (G), IC3.10 (GND), IC3.19 (G), IC4.1 (GND), JP1.1, JP1.12, JP2.1, JP2.11, Q4.2 (S), R8.1, R9.1, R10.2, R11.2, R12.1, U$10.43 (GND), U$10.48 (GND), U$10.49 (GND), U$10.50 (GND), X1.6 (GND), X1.MT1 (GND), X1.MT2 (GND)
IM0: JP2.18, R8.2, SJ1.1, U$10.6 (IM0)
IM1: JP2.17, R9.2, SJ2.1, U$10.7 (IM1)
IM2: JP2.16, R11.1, SJ3.2, U$10.8 (IM2)
IM3: JP2.15, R10.1, SJ4.2, U$10.9 (IM3)
LCD_CS: IC3.15 (B4), U$10.38 (/CS)
LCD_CS_5V: IC3.5 (A4), JP1.3, JP2.7
LCD_DATA0: IC2.18 (B1), U$10.32 (DB0)
LCD_DATA0_5V: IC2.2 (A1), JP1.13
LCD_DATA1: IC2.17 (B2), U$10.31 (DB1)
LCD_DATA1_5V: IC2.3 (A2), JP1.14
LCD_DATA2: IC2.16 (B3), U$10.30 (DB2)
LCD_DATA2_5V: IC2.4 (A3), JP1.15
LCD_DATA3: IC2.15 (B4), U$10.29 (DB3)
LCD_DATA3_5V: IC2.5 (A4), JP1.16
LCD_DATA4: IC2.14 (B5), U$10.28 (DB4)
LCD_DATA4_5V: IC2.6 (A5), JP1.17
LCD_DATA5: IC2.13 (B6), U$10.27 (DB5)
LCD_DATA5_5V: IC2.7 (A6), JP1.18
LCD_DATA6: IC2.12 (B7), U$10.26 (DB6)
LCD_DATA6_5V: IC2.8 (A7), JP1.19
LCD_DATA7: IC2.11 (B8), U$10.25 (DB7)
LCD_DATA7_5V: IC2.9 (A8), JP1.20
LCD_LITE: JP1.8, JP2.10, Q4.1 (G), R5.2, R7.1
LCD_RD: IC3.12 (B7), U$10.35 (/RD)
LCD_RD_5V: IC2.1 (DIR), IC3.8 (A7), JP1.6, R12.2
LCD_RS: IC3.14 (B5), U$10.37 (RS_SCL), X1.5 (SCLK)
LCD_RST: IC3.11 (B8), U$10.10 (/RESET), U$10.47 (TP_RES)
LCD_RST_5V: IC3.9 (A8), IC4.2 (/RESET), JP1.7, JP2.9, R6.1
LCD_RS_5V: IC3.6 (A5), JP1.4, JP2.4
LCD_WR: IC3.13 (B6), U$10.36 (/WR_RS)
LCD_WR_5V: IC3.7 (A6), JP1.5, JP2.8
unnamed: R4.2, U$10.5 (LEDA)
unnamed: R1.2, U$10.2 (LEDA)
unnamed: R2.2, U$10.3 (LEDA)
unnamed: R3.2, U$10.4 (LEDA)
unnamed: Q4.3 (D), U$10.1 (LEDK)
SCL_3V: Q2.2 (S), R16.1, U$10.44 (TP_SCK)
SCL_5V: JP1.10, JP2.14, Q2.3 (D), R13.1
SDA_3V: Q3.2 (S), R15.2, U$10.45 (TP_SDA)
SDA_5V: JP1.11, JP2.13, Q3.3 (D), R14.2
SDI_3V: IC3.16 (B3), U$10.34 (SDI), X1.3 (DATA_IN)
SDI_5V: IC3.4 (A3), JP2.6
SDO: JP2.5, U$10.33 (SDO), X1.7 (DATA_OUT)
SD_CS_3V: IC3.17 (B2), X1.2 (CS)
SD_CS_5V: IC3.3 (A2), JP2.19
VCC: C1.1, C3.1, C4.1, IC1.5 (VOUT), IC2.20 (VCC), IC3.1 (DIR), IC3.20 (VCC), IC4.3 (VCC), JP2.3, Q2.1 (G), Q3.1 (G), R1.1, R2.1, R3.1, R4.1, R5.1, R6.2, R15.1, R16.2, SJ1.2, SJ2.2, SJ3.1, SJ4.1, U$10.40 (IOVCC), U$10.41 (IOVCC), U$10.42 (VCI), X1.4 (SD_VDD)

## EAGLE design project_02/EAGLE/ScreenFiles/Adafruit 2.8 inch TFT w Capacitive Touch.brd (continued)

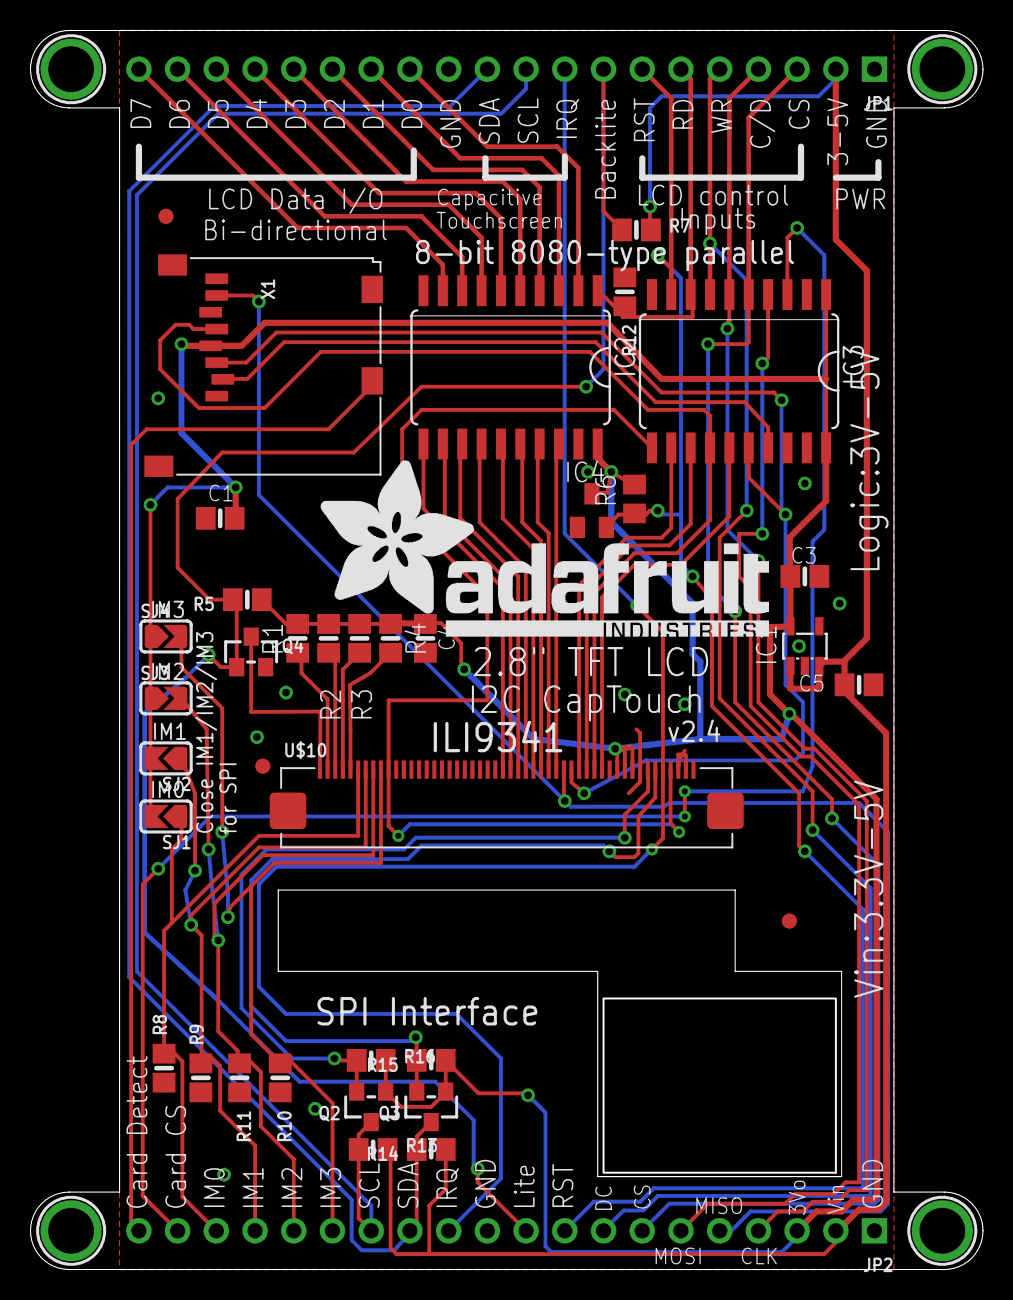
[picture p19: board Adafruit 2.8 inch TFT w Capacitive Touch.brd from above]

Board: 2 copper layers, 62.5 x 81.3 mm, 43 parts (1 on the bottom side), 50 nets.

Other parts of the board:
U$19: ADAFRUIT_TEXT_30MM

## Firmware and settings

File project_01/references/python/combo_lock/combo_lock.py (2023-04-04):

"""
--------------------------------------------------------------------------
Combination Lock
--------------------------------------------------------------------------
License:   
Copyright 2023 - Connor Kelly

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
1. Redistributions of source code must retain the above copyright notice, this 
list of conditions and the following disclaimer.

2. Redistributions in binary form must reproduce the above copyright notice, 
this list of conditions and the following disclaimer in the documentation 
and/or other materials provided with the distribution.

3. Neither the name of the copyright holder nor the names of its contributors 
may be used to endorse or promote products derived from this software without 
specific prior written permission.

THIS SOFTWARE IS PROVIDED BY THE COPYRIGHT HOLDERS AND CONTRIBUTORS "AS IS" 
AND ANY EXPRESS OR IMPLIED WARRANTIES, INCLUDING, BUT NOT LIMITED TO, THE 
IMPLIED WARRANTIES OF MERCHANTABILITY AND FITNESS FOR A PARTICULAR PURPOSE ARE 
DISCLAIMED. IN NO EVENT SHALL THE COPYRIGHT HOLDER OR CONTRIBUTORS BE LIABLE 
FOR ANY DIRECT, INDIRECT, INCIDENTAL, SPECIAL, EXEMPLARY, OR CONSEQUENTIAL 
DAMAGES (INCLUDING, BUT NOT LIMITED TO, PROCUREMENT OF SUBSTITUTE GOODS OR 
SERVICES; LOSS OF USE, DATA, OR PROFITS; OR BUSINESS INTERRUPTION) HOWEVER 
CAUSED AND ON ANY THEORY OF LIABILITY, WHETHER IN CONTRACT, STRICT LIABILITY, 
OR TORT (INCLUDING NEGLIGENCE OR OTHERWISE) ARISING IN ANY WAY OUT OF THE USE 
OF THIS SOFTWARE, EVEN IF ADVISED OF THE POSSIBILITY OF SUCH DAMAGE.
--------------------------------------------------------------------------

Use the following hardware components to make a programmable combination lock:  
  - HT16K33 Display
  - Button
  - Red LED
  - Green LED
  - Potentiometer (analog input)
  - Servo

Requirements:
  - Hardware:
    - When locked:   Red LED is on; Green LED is off; Servo is "closed"; Display is unchanged
    - When unlocked: Red LED is off; Green LED is on; Servo is "open"; Display is "----"
    - Display shows value of potentiometer (raw value of analog input divided by 8)
    - Button
      - Waiting for a button press should allow the display to update (if necessary) and return any values
      - Time the button was pressed should be recorded and returned
    - User interaction:
      - Needs to be able to program the combination for the “lock”
        - Need to be able to input three values for the combination to program or unlock the “lock”
      - Combination lock should lock when done programming and wait for combination input
      - If combination is unsuccessful, the lock should go back to waiting for combination input
      - If combination was successful, the lock should unlock
        - When unlocked, pressing button for less than 2s will re-lock the lock; greater than 2s will allow lock to be re-programmed

Uses:
  - Libraries developed in class

"""
import time

import ht16k33       as HT16K33
import button        as BUTTON
import potentiometer as POT
import servo         as SERVO
import led           as LED
import buzzer as BUZZER

# ------------------------------------------------------------------------
# Constants
# ------------------------------------------------------------------------

SERVO_LOCK         = 100     # Fully anti-clockwise
SERVO_UNLOCK       = 0       # Fully clockwise

POT_DIVIDER        = 8       # Divider used to help reduce potentiometer granularity

# ------------------------------------------------------------------------
# Global variables
# ------------------------------------------------------------------------

# None

# ------------------------------------------------------------------------
# Functions / Classes
# ------------------------------------------------------------------------

class CombinationLock():
    """ CombinationLock """
    reset_time     = None
    button         = None
    red_led        = None
    green_led      = None
    potentiometer  = None
    servo          = None
    display        = None
    debug          = None
    
    def __init__(self, reset_time=2.0, button="P2_2", 
                       red_led="P2_6", green_led="P2_4",
                       potentiometer="P1_19", servo="P1_36", 
                       i2c_bus=1, i2c_address=0x70, buzzer="P2_1"):
        """ Initialize variables and set up display """

        self.reset_time     = reset_time
        self.button         = BUTTON.Button(button)
        self.red_led        = LED.LED(red_led)
        self.green_led      = LED.LED(green_led)
        self.potentiometer  = POT.Potentiometer(potentiometer)
        self.servo          = SERVO.Servo(servo, default_position=SERVO_LOCK)
        self.display        = HT16K33.HT16K33(i2c_bus, i2c_address)
        self.debug          = True
        self.buzzer = BUZZER.Buzzer(buzzer)
        self.music = MUSIC.BuzzerMusic(Buzzer)
        
        self._setup()
    
    # End def
    
    
    def _setup(self):
        """Setup the hardware components."""

        # Initialize Display
        self.set_display_dash()

        # Button / LEDs / Potentiometer / Servo 
        #   - All initialized by libraries when instanitated

    # End def


    def lock(self):
        """Lock the lock:
               - Turn on red LED; Turn off green LED
               - Set servo to closed
        """
        if self.debug:
            print("lock()")
        
        # Set LEDs
        self.red_led.on()
        self.green_led.off()

        # Set servo to "locked"
        self.servo.turn(SERVO_LOCK)

    # End def


    def unlock(self):
        """Unlock the lock.
               - Turn off red LED; Turn on green LED
               - Set servo to open
               - Set display to "----"
        """
        if self.debug:
            print("unlock()")
        
        # Set LEDs
        self.red_led.on()
        self.green_led.off()

        # Set servo to "unlocked"
        self.servo.turn(SERVO_UNLOCK)

        # Set display to dash
        self.set_display_dash()
        
        # Play: "Nocturne of Shadow from The Legend of Zelda"
        self.music.play_song("Nocturne of Shadow from The Legend of Zelda")
        
    # End def


    def show_analog_value(self):
        """Show the analog value on the screen:
               - Read raw analog value
               - Divide by 4 (remove two LSBs)
               - Display value
               - Return value
        """
        if self.debug:
            print("show_analog_value()")
            
        # Read value from Potentiometer
        val = self.potentiometer.get_value()

        # Divide value by POT_DIVIDER
        val = int(val / POT_DIVIDER)

        # Update display (must be an integer)
        self.display.update(int(val))
        
        # Return value
        return val

    # End def


    def input_combination(self):
        """Input a combination for the lock:
               - Wait for a button press doing nothing (start of user inputing combination)
               - Repeat 3 time:
                 - Wait for button press; show analog value
                 - Record analog value
               - Return combination
        """
        # Initialize combination array
        combination = [None, None, None]

        for i in range(3):
            # Update display with current input
            self.set_display_input(i+1)

            # Wait for button press (do nothing)
            # self.button.wait_for_press()
            
            # Variable to record value from button
            press_time = self.button.wait_for_press()

            # Wait for button press (show analog value)
            # !!! FIX !!!
            self.button.wait_for_press(self.show_analog_value)

            # Record Analog value
            combination[i] = self.potentiometer.get_value()

        # print(combination)                       # For debug only
        return combination

    # End def


    def run(self):
        """Execute the main program."""
        combination                  = [None, None, None]  # Combination
        combo_attempt                = [None, None, None]  # Combination attempt
        program                      = True
        
        # Unlock the lock
        self.unlock()        
        time.sleep(1)
                
        while(1):
            time.sleep(1)
            # Program the lock
            if (program):
                if self.debug:
                    print("Program Lock")
                
                # Set display
                self.set_display_prog()
                
                # Wait for button press (do nothing)
                self.button.wait_for_press()
                
                # Get combination
                combination = self.input_combination()
                
                # Lock the lock
                self.lock()
        
                # Set program lock to False
                program = False

            # Set Display to try combination
            self.set_display_try()

            # Wait for button press (do nothing)
            self.button.wait_for_press()
                
            # Get combination
            combo_attempt = self.input_combination()
            

            # Compare attempt against combination
            combo_pass = True

            for i in range(2):
                if combination[i] != combo_attempt[i]:
                    combo_pass = False

            # If combination passed
            if combo_pass:
                if self.debug:
                    print("Combination Passed")
                    
                # Unlock the lock
                self.unlock()

                # Wait for button press (get press time)
                press_time = self.button.wait_for_press()
                
                # If greater than reset_time, program lock, else lock the lock
                if (press_time > self.reset_time):
                    # self.program()
                    combination = self.input_combination()
                else:
                    self.lock()

    # End def


    def set_display_prog(self):
        """Set display to word "Prog" """
        self.display.text("Prog")

    # End def


    def set_display_try(self):
        """Set display to word " go " """
        self.display.text(" go ")

    # End def


    def set_display_input(self, number):
        """Set display to word "in: #" """
        self.display.text("in {0}".format(number))

    # End def


    def set_display_dash(self):
        """Set display to word "----" """
        self.display.text("----")

    # End def


    def cleanup(self):
        """Cleanup the hardware components."""
        
        # Set Display to something fun to show program is complete
        self.display.text("DEAD")

        # Clean up hardware
        # self.button.cleanup()
        self.red_led.cleanup()
        self.green_led.cleanup()
        self.potentiometer.cleanup()
        self.servo.cleanup()

    # End def

# End class


# ------------------------------------------------------------------------
# Main script
# ------------------------------------------------------------------------

if __name__ == '__main__':

    print("Program Start")

    # Create instantiation of the lock
    combo_lock = CombinationLock()

    try:
        # Run the lock
        combo_lock.run()

    except KeyboardInterrupt:
        # Clean up hardware when exiting
        combo_lock.cleanup()

    print("Program Complete")

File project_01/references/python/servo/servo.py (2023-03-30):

"""
--------------------------------------------------------------------------
Servo Driver
--------------------------------------------------------------------------
License:   
Copyright 2021-2023 - <NAME>

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
1. Redistributions of source code must retain the above copyright notice, this 
list of conditions and the following disclaimer.

2. Redistributions in binary form must reproduce the above copyright notice, 
this list of conditions and the following disclaimer in the documentation 
and/or other materials provided with the distribution.

3. Neither the name of the copyright holder nor the names of its contributors 
may be used to endorse or promote products derived from this software without 
specific prior written permission.

THIS SOFTWARE IS PROVIDED BY THE COPYRIGHT HOLDERS AND CONTRIBUTORS "AS IS" 
AND ANY EXPRESS OR IMPLIED WARRANTIES, INCLUDING, BUT NOT LIMITED TO, THE 
IMPLIED WARRANTIES OF MERCHANTABILITY AND FITNESS FOR A PARTICULAR PURPOSE ARE 
DISCLAIMED. IN NO EVENT SHALL THE COPYRIGHT HOLDER OR CONTRIBUTORS BE LIABLE 
FOR ANY DIRECT, INDIRECT, INCIDENTAL, SPECIAL, EXEMPLARY, OR CONSEQUENTIAL 
DAMAGES (INCLUDING, BUT NOT LIMITED TO, PROCUREMENT OF SUBSTITUTE GOODS OR 
SERVICES; LOSS OF USE, DATA, OR PROFITS; OR BUSINESS INTERRUPTION) HOWEVER 
CAUSED AND ON ANY THEORY OF LIABILITY, WHETHER IN CONTRACT, STRICT LIABILITY, 
OR TORT (INCLUDING NEGLIGENCE OR OTHERWISE) ARISING IN ANY WAY OUT OF THE USE 
OF THIS SOFTWARE, EVEN IF ADVISED OF THE POSSIBILITY OF SUCH DAMAGE.
--------------------------------------------------------------------------

SG90 Servo Driver

API:
  Servo(pin)
    - Provide pin that the Servo is connected
  
    turn(percentage)
      -   0 = Fully clockwise
      - 100 = Fully anti-clockwise

"""
import Adafruit_BBIO.PWM as PWM

# ------------------------------------------------------------------------
# Constants
# ------------------------------------------------------------------------

SG90_FREQ               = 50                  # 20ms period (50Hz)
SG90_POL                = 0                   # Rising Edge polarity
SG90_MIN_DUTY           = 5                   # 1ms pulse (5% duty cycle)  -- Fully clockwise (right)
SG90_MAX_DUTY           = 10                  # 2ms pulse (10% duty cycle) -- Fully anti-clockwise (left)

# ------------------------------------------------------------------------
# Global variables
# ------------------------------------------------------------------------

# None

# ------------------------------------------------------------------------
# Functions / Classes
# ------------------------------------------------------------------------

class Servo():
    """ CombinationLock """
    pin       = None
    position  = None
    
    def __init__(self, pin=None, default_position=0):
        """ Initialize variables and set up the Servo """
        if (pin == None):
            raise ValueError("Pin not provided for Servo()")
        else:
            self.pin = pin

        self.position = default_position
        
        self._setup(default_position)
    
    # End def
    
    
    def _setup(self, default_position):
        """Setup the hardware components."""
        # Initialize Servo; Servo should be "off"
        
        # !!! NEED TO IMPLEMENT !!! #
        PWM.start(self.pin, SG90_MIN_DUTY, SG90_FREQ, SG90_POL)
        pass 
        # !!! NEED TO IMPLEMENT !!! #
        
        # Set default position
        self.turn(default_position)

    # End def

    
    def get_position(self):
        """ Return the position of the servo """
        return self.position
    
    # End def
    

    def turn(self, position):
        """ Turn Servo to the desired position based on percentage of motion range
        
              0% = Fully clockwise (right)
            100% = Fully anti-clockwise (left)      
        """
        # Record the current position
        self.position = position
        
        # Set PWM duty cycle based on position
        duty_cycle = ((SG90_MAX_DUTY - SG90_MIN_DUTY) * (position / 100)) + SG90_MIN_DUTY
        
        # !!! NEED TO IMPLEMENT !!! #
        print("Turning servo to position {0} using duty cycle {1}".format(position, duty_cycle))
        
        PWM.set_duty_cycle(self.pin, duty_cycle)
        
        # !!! NEED TO IMPLEMENT !!! #

    # End def


    def cleanup(self):
        """Cleanup the hardware components."""
        # Stop servo
        PWM.stop(self.pin)
        PWM.cleanup()
        
    # End def

# End class



# ------------------------------------------------------------------------
# Main script
# ------------------------------------------------------------------------

if __name__ == '__main__':
    import time
    
    print("Servo Test")

    # Create instantiation of the servo
    servo = Servo("P1_36")

    # Use a Keyboard Interrupt (i.e. "Ctrl-C") to exit the test
    print("Use Ctrl-C to Exit")
    
    try:
        while(1):
            # Turn Servo anti-clockwise
            servo.turn(0)
            print("Current position = {0}%".format(servo.get_position()))
            time.sleep(1)
        
            servo.turn(100)
            print("Current position = {0}%".format(servo.get_position()))
            time.sleep(1)
        
    except KeyboardInterrupt:
        pass

    # Clean up hardware when exiting
    servo.cleanup()

    print("Test Complete")

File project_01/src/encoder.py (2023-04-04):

"""
Original Code from: 
Encoder library for Raspberry Pi for measuring quadrature encoded signals.
created by Mivallion <mivallion@gmail.com>
Version 1.0 - 01 april 2020 - inital release

Modified by Connor Kelly May 2023 <cjk7@rice.edu>
"""

# import RPi.GPIO as GPIO
import Adafruit_BBIO.GPIO as GPIO
import time

class Encoder(object):
    """
    Encoder class allows to work with rotary encoder
    which connected via two pin A and B.
    Works only on interrupts because all RPi pins allow that.
    This library is a simple port of the Arduino Encoder library
    (https://github.com/PaulStoffregen/Encoder) 
    """
    def __init__(self, A, B):
        # GPIO.setmode(GPIO.BCM)
        GPIO.setup(A, GPIO.IN)
        GPIO.setup(B, GPIO.IN)
        self.A = A
        self.B = B
        self.pos = 0
        self.state = 0
        if GPIO.input(A):
            self.state |= 1
        if GPIO.input(B):
            self.state |= 2
        # GPIO.add_event_detect(A, GPIO.BOTH, callback=self.__update)
        # GPIO.add_event_detect(B, GPIO.BOTH, callback=self.__update)
        # GPIO.add_event_detect(A, GPIO.BOTH, callback=self.__update)
        # GPIO.add_event_detect(B, GPIO.BOTH, callback=self.__update)
        
            

    """
    update() calling every time when value on A or B pins changes.
    It updates the current position based on previous and current states
    of the rotary encoder.
    """
    def __update(self, channel = 0):
        print("updating\n")
        print("Pin A: %d"%GPIO.input(self.A))
        print("Pin B: %d"%GPIO.input(self.B))
        
        state = self.state & 3
        if GPIO.input(self.A):
            state |= 4
        if GPIO.input(self.B):
            state |= 8

        self.state = state >> 2

        if state == 1 or state == 7 or state == 8 or state == 14:
            self.pos += 1
        elif state == 2 or state == 4 or state == 11 or state == 13:
            self.pos -= 1
        elif state == 3 or state == 12:
            self.pos += 2
        elif state == 6 or state == 9:
            self.pos -= 2


    """
    read() simply returns the current position of the rotary encoder.
    """
    def read(self):
        self.__update()
        return self.pos
        
    # while (True):
            # self.__update()

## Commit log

2023-02-13 tested on-board, all working
2023-03-05 added sample muisc
2023-04-02 added sample directory
2023-04-02 laptop push, created m3u.ipynb to prototype playlist parsing
2023-05-03 added pcb things
    [Adafruit 2.8 inch TFT w Capacitive Touch.brd, Adafruit 2.8 inch TFT w Capacitive Touch.sch, PocketBeagle.brd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]
